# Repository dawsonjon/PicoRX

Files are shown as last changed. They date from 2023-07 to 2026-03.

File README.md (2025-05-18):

Pi Pico Rx - A crystal radio for the digital age?
=================================

My first step into the world of electronics was with a crystal radio, just like this one. 

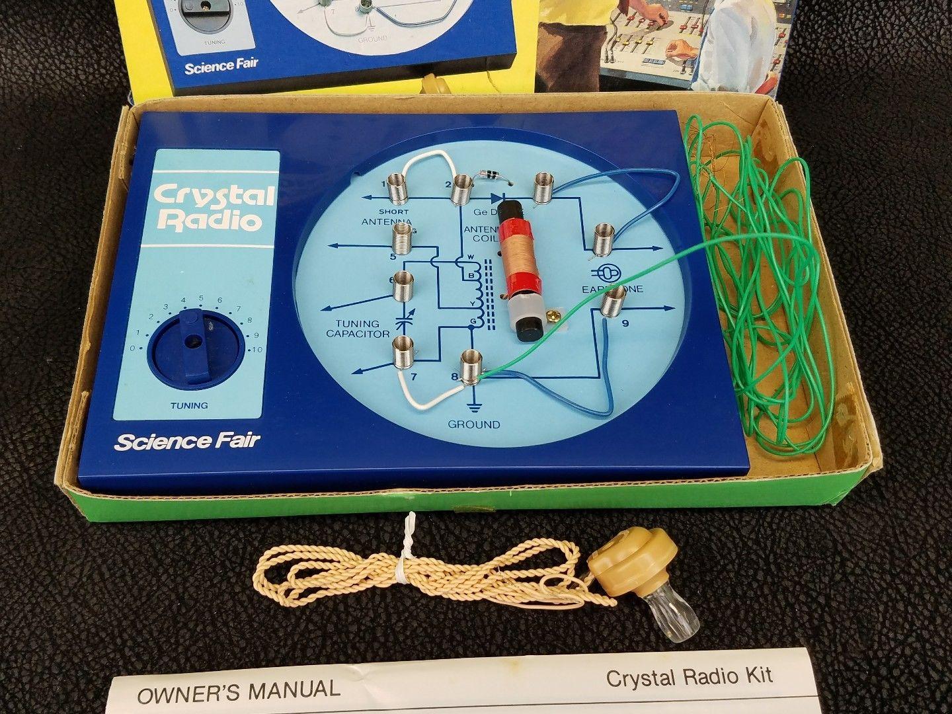
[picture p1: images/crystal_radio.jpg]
crystal radio


Back then, I don't think it has ever occurred to me that I could make a radio myself, so I wasn't expecting it to work. But when I put the earphone in, I was amazed to hear very faint sounds coming through. I couldn't believe that building a radio could be so simple, and the best part was, it didn't need any batteries! That little experience sparked my interest in electronics.

Times have certainly changed since then, and today, we find ourselves in a golden age for electronics enthusiasts. Back in the ninteen eightees, I could have never imagined that my pocket money would one day buy a device with computing power that could have filled an entire room just a few decades ago.

I often wonder how we can still capture that sense of awe and excitement from my first crystal radio experience. Is it still possible to create something simple yet captivating? 

The Pi Pico Rx - may be the answer to that question. While it may not be quite as straightforward as the crystal radio, the Pi Pico Rx presents a remarkably simple solution. Armed with just a [Raspberry Pi Pico](https://www.raspberrypi.com/products/raspberry-pi-pico/), an analogue switch, and an op-amp, we now have the power to construct a capable SDR receiver covering the LW, MW, and SW bands. With the ability to receive signals from halfway around the globe. I can't help but think that my younger self would have been truly impressed!

concept

Features
--------

+ 0 - 30MHz coverage
+ 250kHz bandwidth SDR reciever
+ CW/SSB/AM/FM reception
+ OLED display
+ simple spectrum scope
+ Headphones/Speaker
+ 500 general purpose memories
+ runs on 3 AAA batteries
+ less than 50mA current consumption

Development
-----------

concept

Pi Pico Rx is currently at the experimental prototyping stage, but it does work. [Read the Docs](https://101-things.readthedocs.io/en/latest/radio_receiver.html) for more technical details!

Getting the Code
----------------

You can find a precompiled binary for PiPicoRx [here](https://github.com/dawsonjon/PicoRX/releases). If you want to build from the C++ source files, follow these instructions.

```
  sudo apt install git
  git clone https://github.com/dawsonjon/PicoRX.git
  cd PicoRX
  git submodule init
  git submodule update
```

User Manual
-----------

You can find the user manual for the PiPicoRx [here](https://github.com/dawsonjon/PicoRX/raw/master/user_manual/Pi%20Pico%20Rx%20User%20Manual.pdf).

Install Pi Pico SDK
-------------------

Follow the [Getting started with the Raspberry Pi Pico](https://datasheets.raspberrypi.com/pico/getting-started-with-pico.pdf) quick start guide to install the C/C++ SDK.

```
  sudo apt install wget #if wget not installed
  wget https://raw.githubusercontent.com/raspberrypi/pico-setup/master/pico_setup.sh
  chmod +x pico_setup.sh
  ./pico_setup.sh
```

For windows users, this page provides and [installer](https://www.raspberrypi.com/news/raspberry-pi-pico-windows-installer/) that makes the process much simpler.

Build Projects
--------------

```
  mkdir build
  cd build
  cmake -DPICO_BOARD=pico -DPICO_SDK_PATH=~/pico/pico-sdk ..
  make
```

```
  mkdir build
  cd build
  cmake -DPICO_SDK_PATH=~/pico/pico-sdk -DPICO_BOARD=pico2 -DPICO_PLATFORM=rp2350-arm-s ..
  make
```

```
  mkdir build
  cd build
  cmake -DPICO_SDK_PATH=~/pico/pico-sdk -DPICO_BOARD=pico2 -DPICO_PLATFORM=rp2350-riscv ..
  make
```

Credits
-------

Massive thanks to everybody who has contributed and given feedback on this project. Thanks to
all your efforts, we’re closer than ever to making radio more accessible,
innovative, and community-driven.

The project uses the Universal 8-bit Graphics Library (u8g2) library by
olikraus@gmail.com, the pico_ssd1306 display library by David Schramm and the
ILI934X display driver by Darren Horrocks.

Special Thanks to:

Mariusz Ryndzionek for contributing IQ Imbalance Correction, De-emphasis
filter, USB audio, U8G2 integration, Synronous AM Demodulation and many other
enhancements.

Penfold42 for Gain Calibration, Frequency Scanning, Spectrum Zoom, Multiple home screen
views, Animated Splash Screen, Support for multiple displays/configurations and
many other enhancements.

Robert Nickels (W9RAN) and Jim Reagan (W0CHL) for their support and
encouragements and for the enormous effort they have both put in testing,
debugging, feedback and suggestions.

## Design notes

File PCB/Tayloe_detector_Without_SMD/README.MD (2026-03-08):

A Tayloe Detector Without SMD components
========================================

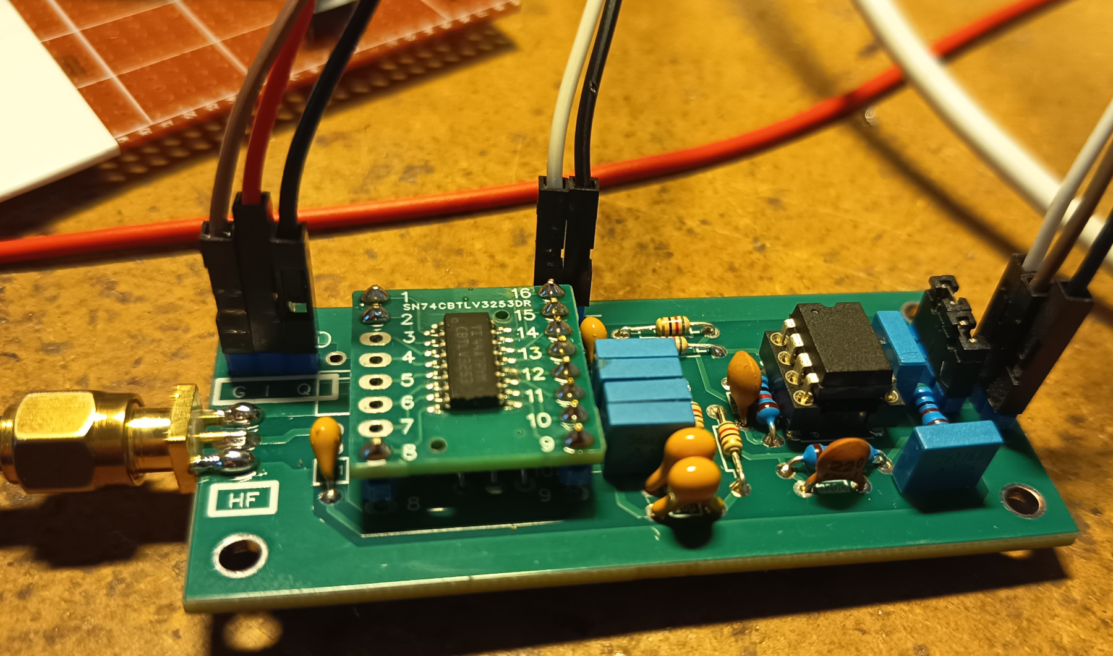
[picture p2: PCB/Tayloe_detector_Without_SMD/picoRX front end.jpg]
picoRX front end


This detector was built using traditional (through-hole) components in order to carry out tests and measurements on PicoRX. It includes the latest improvements to the receiver (anti-aliasing).
The 74CBTLV3253 is mounted on a SOIC16 to DIP16 adapter.

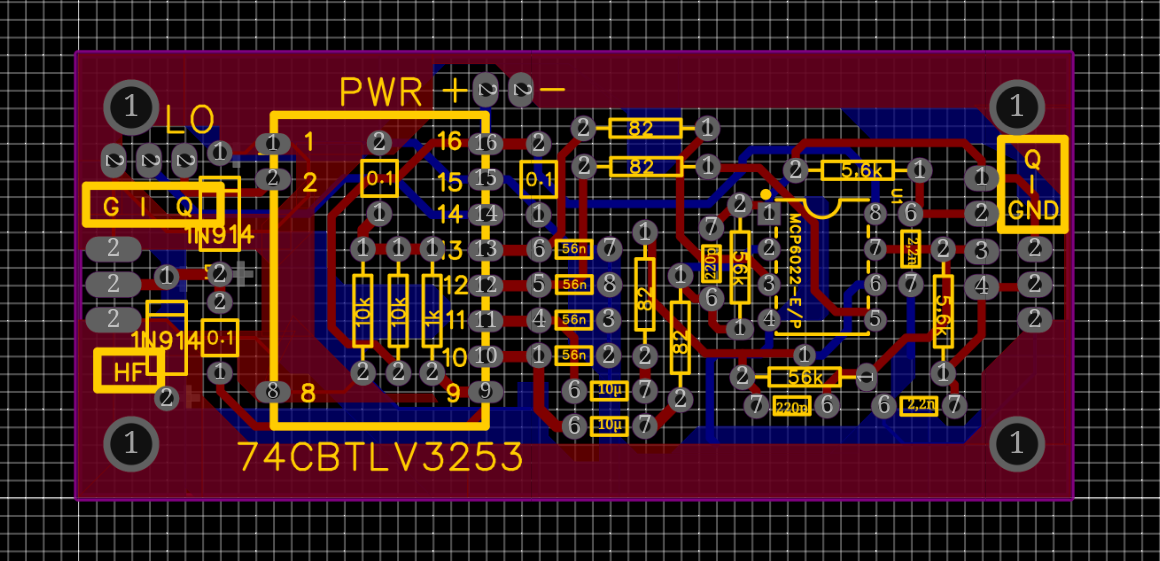
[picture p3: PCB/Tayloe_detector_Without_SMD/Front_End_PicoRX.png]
picoRX front end


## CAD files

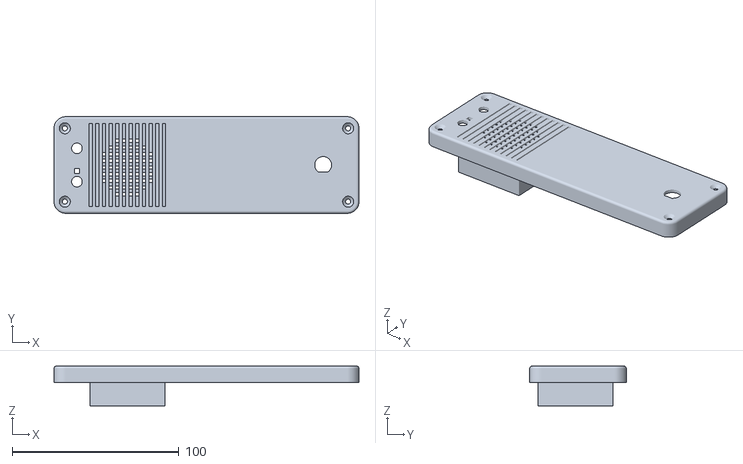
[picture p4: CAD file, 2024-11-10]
enclosure/breadboard_version/breadboard_radio-Partback_panel_tft.stl
183.0 x 58.0 x 24.0

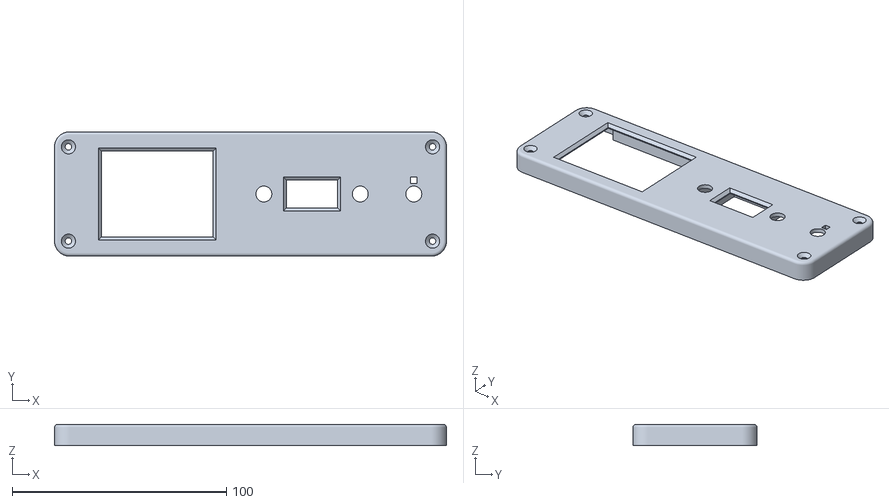
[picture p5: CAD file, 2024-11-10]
enclosure/breadboard_version/breadboard_radio-Partfront_panel_tft.stl
183.0 x 58.0 x 10.0

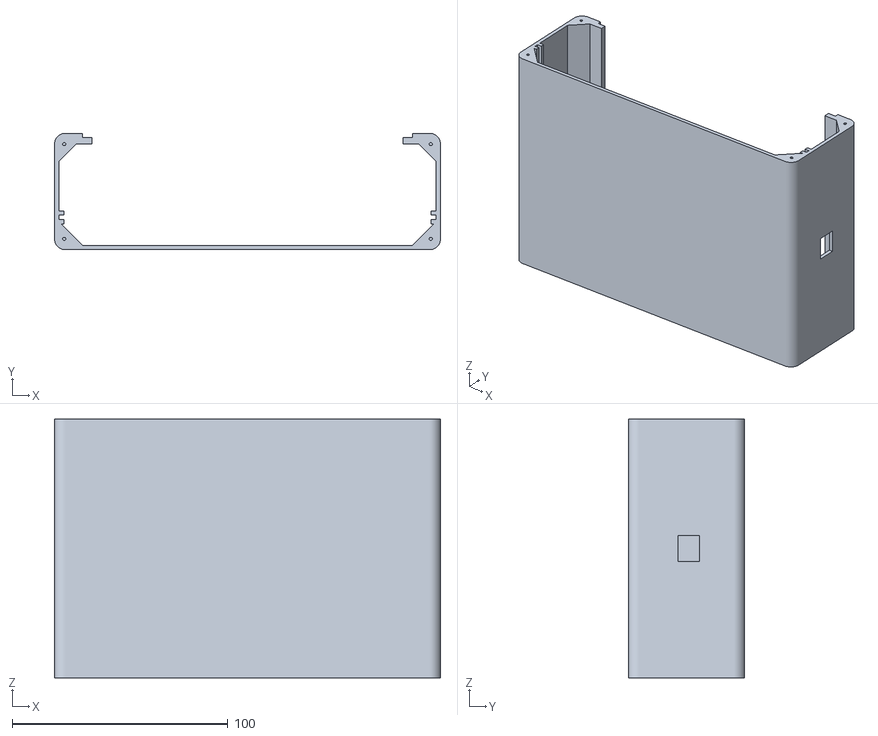
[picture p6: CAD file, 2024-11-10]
enclosure/breadboard_version/breadboard_radio-Partbox.stl
179.0 x 54.0 x 120.0

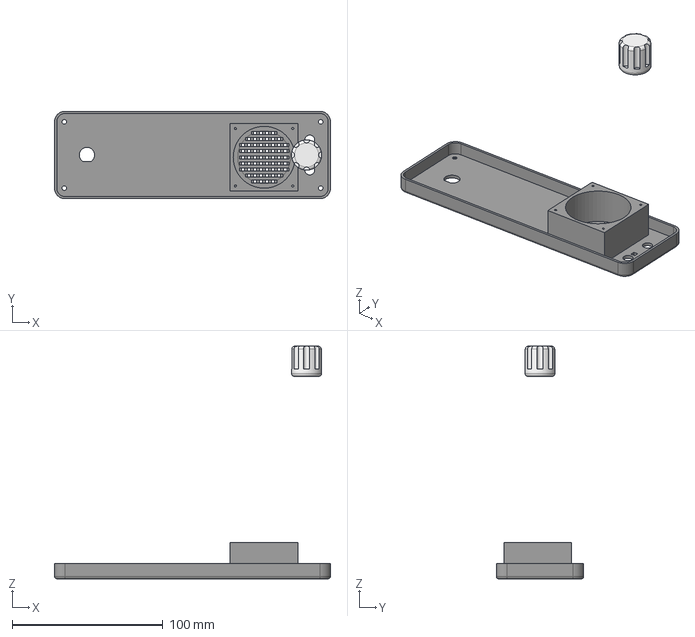
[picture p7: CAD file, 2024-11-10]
enclosure/breadboard_version/breadboard_radio.FCStd
183.0 x 58.0 x 154.2 mm
back_panel_tft
knob

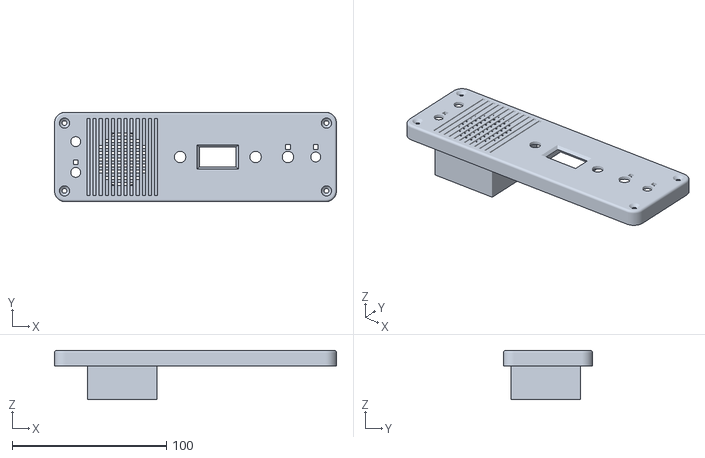
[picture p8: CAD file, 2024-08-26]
enclosure/breadboard_version/breadboard_radio-Partfront_panel.stl
183.0 x 58.0 x 32.0

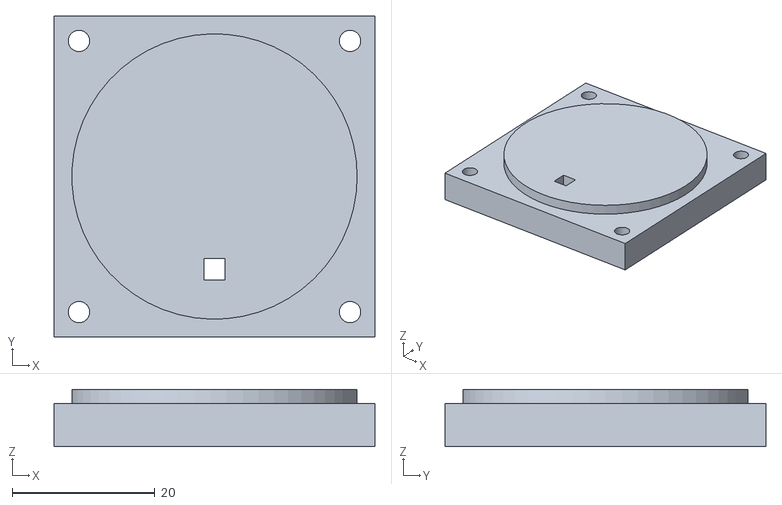
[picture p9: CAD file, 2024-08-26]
enclosure/breadboard_version/breadboard_radio-PartSpeakerLid.stl
45.0 x 45.0 x 8.00

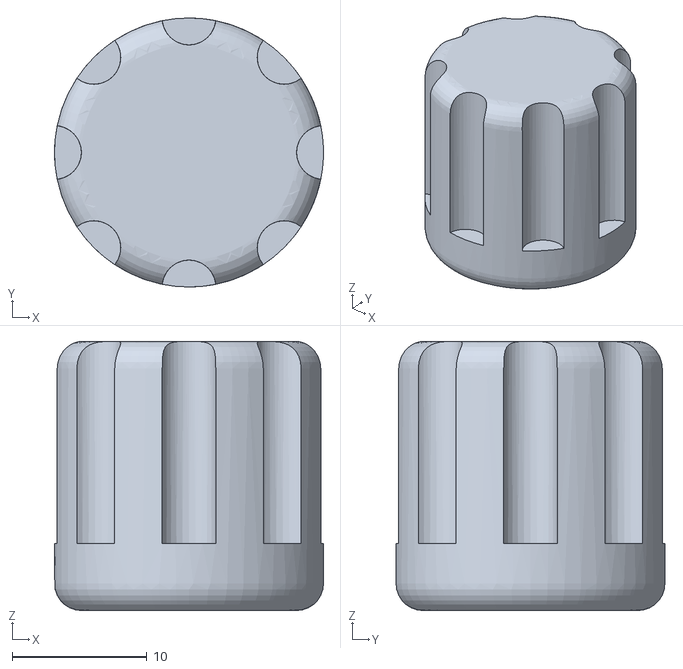
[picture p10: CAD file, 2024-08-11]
enclosure/breadboard_version/breadboard_radio-knob.stl
20.0 x 20.0 x 20.0

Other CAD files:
enclosure/breadboard_version/breadboard_radio-Partback panel.stl
enclosure/breadboard_version/breadboard_radio-Partback_panel.stl

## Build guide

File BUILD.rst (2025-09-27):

Pi Pico Rx - Build Instructions
"""""""""""""""""""""""""""""""

Getting the Code
----------------

.. code::

  sudo apt install git
  git clone https://github.com/dawsonjon/PicoRX.git
  cd PicoRX
  git submodule init
  git submodule update

Install Build Dependencies
--------------------------

Install the following packages using your distributions package manager:

- `cmake`
- `gcc-arm-none-eabi`

For Ubuntu and other Debian based Linux distributions, the following command
line can be used to install all dependencies at once.

.. code::

  sudo apt install git cmake gcc-arm-none-eabi

Install Pi Pico SDK (Optional)
------------------------------

This step is now optional and only necessary if offline (no internet) builds
are desired. If this step is skipped, the configure step of the CMake build will
pull down the necessary Pico SDK dependencies.

Follow the `Getting started with the Raspberry Pi Pico <https://datasheets.raspberrypi.com/pico/getting-started-with-pico.pdf>`_ quick start guide to install the C/C++ SDK.

.. code::

  sudo apt install wget #if wget not installed
  wget https://raw.githubusercontent.com/raspberrypi/pico-setup/master/pico_setup.sh
  chmod +x pico_setup.sh
  ./pico_setup.sh

Build Project
-------------

Build the project using these cmake commands.

.. code::

  mkdir build
  cd build
  cmake -DPICO_BOARD=pico ..
  make

**NOTE**: When using the installed SDK described in the previous section, ensure
the ``PICO_SDK_PATH`` environment variable exists on your path by running:
``echo ${PICO_SDK_PATH}``. If the output is empty, refresh the environment by
either starting a new shell or by running: ``source ~/.bashrc``.

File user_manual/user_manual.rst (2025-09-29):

.. header::
  Pi Pico Rx User Manual

.. footer::
  Revision 2 Copyright (C) Jonathan P Dawson 2025

  Page ###Page### of ###Total###

Pi Pico RX - User Manual
########################

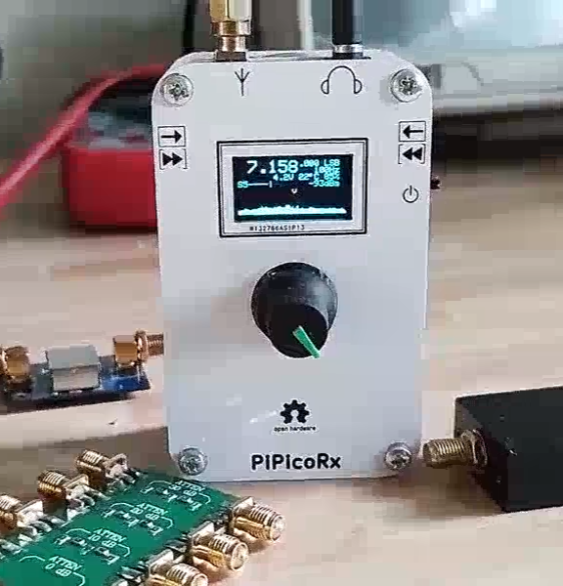
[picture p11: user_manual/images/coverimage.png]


.. raw:: pdf

   PageBreak

.. sectnum::

.. contents::

.. raw:: pdf

   PageBreak

Home Screen
===================

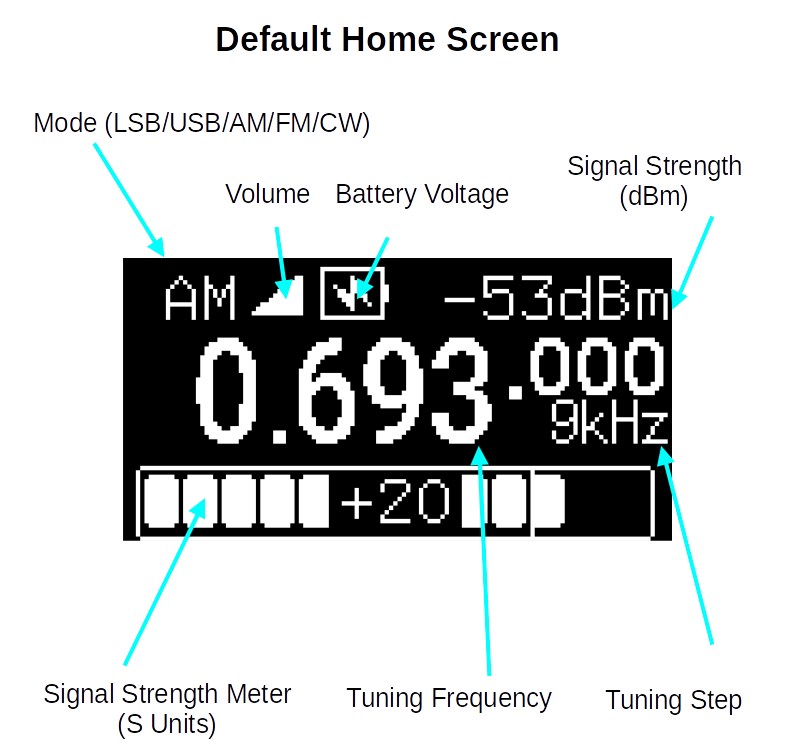
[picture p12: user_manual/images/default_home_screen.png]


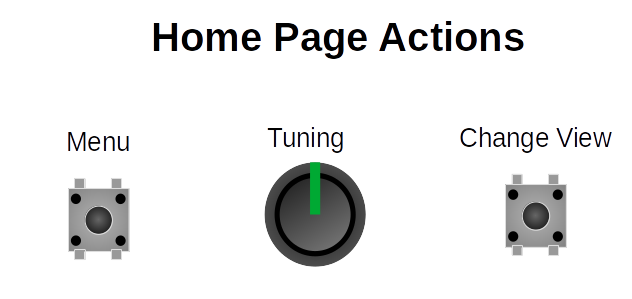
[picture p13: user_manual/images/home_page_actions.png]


Views
------

Views include spectrum scope, waterfall, status info, memory scan, frequency scan etc.

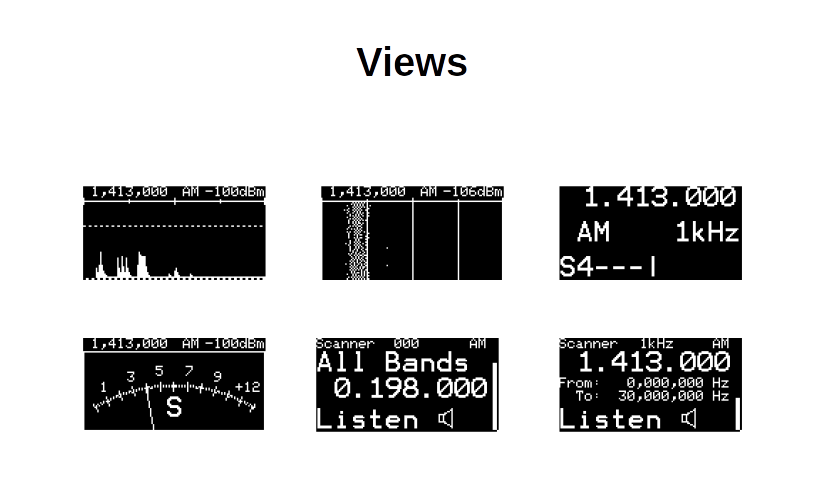
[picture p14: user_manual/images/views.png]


Tuning
------

+-------------------------------------------+----------------------------------------+
| Shortcut                                  |          Description                   |
+===========================================+========================================+
| Encoder Rotate                            |        Tuning Up/Down                  |
+-------------------------------------------+----------------------------------------+
| Encoder Rotate + Menu held                |      Tuning Up/Down x10                |
+-------------------------------------------+----------------------------------------+
| Encoder Rotate + Back held                |      Tuning Up/Down /10                |
+-------------------------------------------+----------------------------------------+
| Encoder Rotate + Menu held + Back held    |      Tuning Up/Down x100               |
+-------------------------------------------+----------------------------------------+

Shortcuts
---------

+-------------------------------------------+----------------------------------------+
| Shortcut                                  |          Description                   |
+===========================================+========================================+
| Encoder Rotate                            |        Tuning Up/Down                  |
+-------------------------------------------+----------------------------------------+
| Encoder Rotate + Menu held                |      Tuning Up/Down x10                |
+-------------------------------------------+----------------------------------------+
| Encoder Rotate + Menu held + Back held    |      Tuning Up/Down /10                |
+-------------------------------------------+----------------------------------------+
| Encoder Rotate + Menu held + Back held    |      Tuning Up/Down x100               |
+-------------------------------------------+----------------------------------------+
| Encoder Rotate + Encoder Held             |        Volume Up/Down                  |
+-------------------------------------------+----------------------------------------+
| Encoder Rotate + Encoder Held + Menu Held | Mode Select (AM/AMS/FM/CW/LSB/USB)     |
+-------------------------------------------+----------------------------------------+
| Encoder Rotate + Encoder Held + Back Held |         Squelch Up/Down                |
+-------------------------------------------+----------------------------------------+

.. raw:: pdf

   PageBreak

Auxiliary TFT Display (Optional)
================================

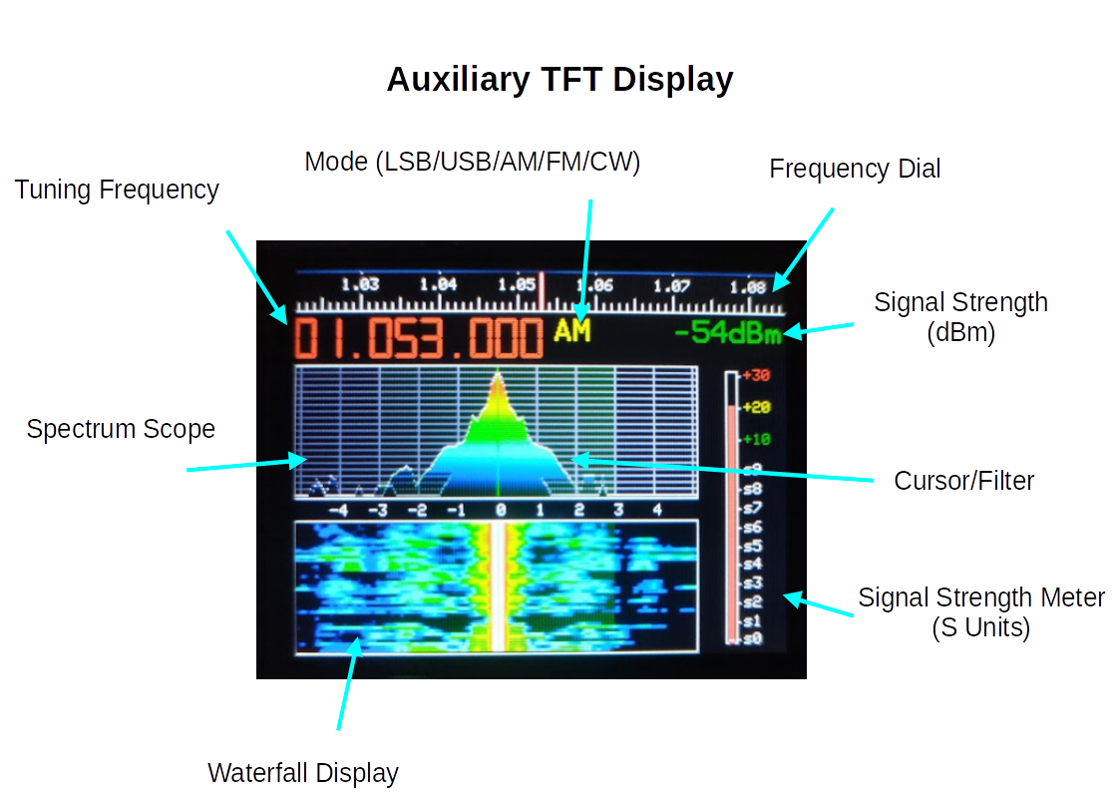
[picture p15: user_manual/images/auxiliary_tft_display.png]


Main Menu
=========

Radio functions and configuration are accessed through the main menu.

+------------------+--------------------------+--------------------------------------------------------------------------------------------------------------------+
| Setting          | Range                    | Description                                                                                                        |
+==================+==========================+====================================================================================================================+
| Frequency        | 0-30 MHz                 | Manual Frequency Entry. Selecting a frequency outside the current band will reset the band limits to               |
|                  |                          | allow free-tuning across the full frequency range.                                                                 |
+------------------+--------------------------+--------------------------------------------------------------------------------------------------------------------+
| Memory Recall    | 0-511                    | Select One of 512 memory channels (A channel can be a single frequency or a band of interest)                      |
+------------------+--------------------------+--------------------------------------------------------------------------------------------------------------------+
| Memory Store     | 0-511                    | Save the current frequency, mode etc. in one of 512 memory channels                                                |
+------------------+--------------------------+--------------------------------------------------------------------------------------------------------------------+
| Volume           | 0-9                      | Audio Volume 0=mute                                                                                                |
+------------------+--------------------------+--------------------------------------------------------------------------------------------------------------------+
| Mode             |                          | Receiver mode (AM, AMS, FM, LSB, USB, CW)                                                                          |
+------------------+--------------------------+--------------------------------------------------------------------------------------------------------------------+
| AGC              | Very Slow – Fast, Manual | Automatic gain control adjusts the gain so that weak and strong stations have a similar volume level.              |
|                  |                          | Fast settings respond quickly to changes in signal level, slow settings change more gradually.                     |
|                  |                          | A slow setting might prevent adjustments to gain during gaps in speech. Manual gain control is also                |
|                  |                          | possible, this might be useful when a constant gain is desirable, e.g. when working with digital modes.            |
+------------------+--------------------------+--------------------------------------------------------------------------------------------------------------------+
| AGC Gain         | 0dB to 60dB              | In Manual mode, this settings specifies the gain directly. In other modes, this setting specifies the              |
|                  |                          | maximum gain limit for the AGC.  Note: If you set a low gain value might prevent weak signals being                |
|                  |                          | heard, if the receiver seems deaf, check this setting!                                                             |
+------------------+--------------------------+--------------------------------------------------------------------------------------------------------------------+
| Bandwidth        | Very Narrow – Very Wide  | Adjust the filter bandwidth, a narrow setting reduces background noise and can improve intelligibility             |
|                  |                          | of weak signals. A wider settings allows through a greater range of frequencies giving better sound                |
|                  |                          | quality for strong signals.                                                                                        |
+------------------+--------------------------+--------------------------------------------------------------------------------------------------------------------+
| Squelch          | S0 - S9+30dB             | The squelch function gates background noise. The signal is muted unless the signal strength reaches                |
|                  |                          | a defined level. Squelch can be adjusted to allow signals to be audible when active, but remove                    |
|                  |                          | background noise when inactive.                                                                                    |
+------------------+--------------------------+--------------------------------------------------------------------------------------------------------------------+
| Squelch Timeout  | 50ms-5s                  | This setting specifies the timeout for the squelch function. When a signal falls below the squelch                 |
|                  |                          | threshold it will continue to be heard until the timeout expires.                                                  |
+------------------+--------------------------+--------------------------------------------------------------------------------------------------------------------+
| Noise Reduction  |                          | Noise Reduction Menu                                                                                               |
+------------------+--------------------------+--------------------------------------------------------------------------------------------------------------------+
| Impulse Blanker  |                          | Enable impulse blanker and set threshold. The impulse blanker can mitigate some types of noise (e.g. from car      |
|                  |                          | ignition circuits, electric fences etc. Threshold values vary from 2.0 to 3.0.                                     |
+------------------+--------------------------+--------------------------------------------------------------------------------------------------------------------+
| Auto Notch       | On/Off                   | The automatic notch filter can be used to remove interfering tones. If stable interference is detected             |
|                  |                          | consistently at the same frequency, a narrow notch is enabled to automatically suppress the interference.          |
+------------------+--------------------------+--------------------------------------------------------------------------------------------------------------------+
| De-Emphasis      | Off/50us/75us            | Enable de-emphasis filter                                                                                          |
+------------------+--------------------------+--------------------------------------------------------------------------------------------------------------------+
| Bass             | Off, 5-20dB              | Bass tone control                                                                                                  |
+------------------+--------------------------+--------------------------------------------------------------------------------------------------------------------+
| Treble           | Off, 5-20dB              | Treble tone control                                                                                                |
+------------------+--------------------------+--------------------------------------------------------------------------------------------------------------------+
| IQ-Correction    | On/Off                   | Compensates for differences in phase/magnitude in the IQ inputs. Enable this setting to improve image              |
|                  |                          | rejection (remove mirror frequencies)                                                                              |
+------------------+--------------------------+--------------------------------------------------------------------------------------------------------------------+
| Spectrum         |                          | Spectrum Menu                                                                                                      |
+------------------+--------------------------+--------------------------------------------------------------------------------------------------------------------+
| Aux Display      | Waterfall/SSTV Decode    | Switch between views in auxiliary (TFT) display (if fitted)                                                        |
+------------------+--------------------------+--------------------------------------------------------------------------------------------------------------------+
| Band Start/Stop  | 0-30MHz                  | The band-start and band-stop settings define the tuning range of the current band. The band-start and              |
|                  |                          | band stop settings are stored in memory channels allowing memory channels to hold bands as well as                 |
|                  |                          | individual frequencies.                                                                                            |
+------------------+--------------------------+--------------------------------------------------------------------------------------------------------------------+
| Frequency Step   | 10Hz-100kHz              | Set the default tuning step. Note that fast and slow tuning from /10 to \*100 the nominal frequency                |
|                  |                          | step can be achieved by holding the menu/back buttons.                                                             |
+------------------+--------------------------+--------------------------------------------------------------------------------------------------------------------+
| CW Tone          | 100Hz - 3000Hz           | When received, the CW signal has a very narrow bandwidth close to DC, lower than the range of human hearing.       |
|                  |                          | The CW tone increases the frequency of the CW signal to a frequency that can be heard comfortably A frequency      |
|                  |                          | between 500Hz and 1000Hz is typical.                                                                               |
+------------------+--------------------------+--------------------------------------------------------------------------------------------------------------------+
| USB Stream       | Audio/IQ                 | Two USB streaming modes are supported. In audio mode, the device is configured as a mono USB                       |
|                  |                          | microphone. In this mode, the demodulated audio is streamed via USB, e.g. for sound recording or for               |
|                  |                          | use with digi-mode apps such as fldigi or wsjtx. In IQ mode, raw IQ data is streamed via USB as a                  |
|                  |                          | stereo stream. In this mode the device can be used with SDR software such as quisk or gqrx.                        |
+------------------+--------------------------+--------------------------------------------------------------------------------------------------------------------+
| HW Configuration |                          | The Pi Pico RX is designed to be as flexible as possible to allow different configurations and                     |
|                  |                          | experimentation by constructors. A separate hardware configuration menu is provided to configure the hardware.     |
+------------------+--------------------------+--------------------------------------------------------------------------------------------------------------------+

Spectrum Menu
=============

+------------------+--------------------------+--------------------------------------------------------------------------------------------------------------------+
| Setting          | Range                    | Description                                                                                                        |
+==================+==========================+====================================================================================================================+
| Spectrum Zoom    | 1-4                      | Zoom level for spectrum scope. 1=30kHz, 2=15kHz, 3=7.5kHz, 4=3.75kHz                                               |
+------------------+--------------------------+--------------------------------------------------------------------------------------------------------------------+
| Spectrum         | 1-4                      | Time Domain Smoothing (averaging) 1=least smoothing 4 = most smoothing                                             |
| Smoothing        |                          |                                                                                                                    |
+------------------+--------------------------+--------------------------------------------------------------------------------------------------------------------+

Noise Reduction
===============

+------------------+---------------------------+--------------------------------------------------------------------------------------------------------------------+
| Setting          | Range                     | Description                                                                                                        |
+==================+===========================+====================================================================================================================+
| Enable           | 1-4                       | Zoom level for spectrum scope. 1=30kHz, 2=15kHz, 3=7.5kHz, 4=3.75kHz                                               |
+------------------+---------------------------+--------------------------------------------------------------------------------------------------------------------+
| Noise            | Very Fast - Very Slow     | Timescale for noise estimation. A fast setting allows the algorithms to adapt to fast changes in noise level.      |
| Estimation       |                           | A slow setting gives a more stable noise measurement.                                                              |
+------------------+---------------------------+--------------------------------------------------------------------------------------------------------------------+
| Noise            | Adaptive, Low - Very High | A high setting removes more noise, but may also remove some signal. The adaptive setting removes more noise when   |
| Threshold        |                           | and uses a less agressive setting in low-noise environments.                                                       |
+------------------+---------------------------+--------------------------------------------------------------------------------------------------------------------+

Hardware Configuration Menu
===========================

+--------------------+-------------------------------+------------------------------------------------------------------------------------------------------------+
| Setting            | Range                         |  Description                                                                                               |
+--------------------+-------------------------------+------------------------------------------------------------------------------------------------------------+
| Tuning Options     | None, Tristate, Ground        |  During retuning, the PLL within the Pi Pico is adjusted to allow the closest possible NCO frequency to be |
|                    |                               |  selected. As the PLL is adjusted, the clock speed within the pico temporarily dips, this causes the PWM   |
|                    |                               |  pulses in the audio output to lengthen, causing an audible click or pop. To mitigate against this, the    |
|                    |                               |  PWM output can be disabled during tuning. There are 2 methods to achieve this, the GPIO pin can be either |
|                    |                               |  tristated, or grounded. The grounding method gives slightly improved click suppression at the expense of  |
|                    |                               |  tuning speed.                                                                                             |
+--------------------+-------------------------------+------------------------------------------------------------------------------------------------------------+
| Display Timeout    | Never, 5 seconds – 4 minutes  |  Display turns off after a period of inactivity. This can be useful for power saving when running from     |
|                    |                               |  batteries. This may also help prevent noise being generated by the display being received.                |
+--------------------+-------------------------------+------------------------------------------------------------------------------------------------------------+
| Regulator Mode     | FM/PWM                        |  The Pi Pico contains a switched-mode regulator. Under light loading, the regulator can switch into a FM   |
|                    |                               |  mode to save power, this does however increase supply ripple. The PWM setting reduces supply ripple.      |
+--------------------+-------------------------------+------------------------------------------------------------------------------------------------------------+
| Reverse Encoder    | On/Off                        |  This allows the direction of the encoder to be reversed (clockwise/anticlockwise). This allows for        |
|                    |                               |  variations in hardware construction where the encoder is wired in a different configuration.              |
+--------------------+-------------------------------+------------------------------------------------------------------------------------------------------------+ 
| Encoder Resolution | On/Off                        |  Allows higher resolution rotary encoders to be used.                                                      |
+--------------------+-------------------------------+------------------------------------------------------------------------------------------------------------+
| Swap IQ            | On/Off                        |  Swap the I/Q ADC input channels. Can be used to correct for a difference in wiring of the LO inputs,      |
|                    |                               |  or IQ inputs. It causes the received spectrum to be reversed so that positive frequencies become negative |
|                    |                               |  and vice-versa. This is also useful for checking image rejection.                                         |
+--------------------+-------------------------------+------------------------------------------------------------------------------------------------------------+
| Gain Cal           | 1-100dB                       |  Specifies the gain of the receiver, this is used by the software to calculate the signal strength for the |
|                    |                               |  S-meter and dBm signal strength. The breadboard version of the receiver with default components has a     |
|                    |                               |  gain of 57dB. Constructors may use alternative gain values, additional filters or preamplifiers. This     |
|                    |                               |  setting also allows the S-meter to be calibrated so that it reads the correct signal strength with a      |
|                    |                               |  known input signal.                                                                                       |
+--------------------+-------------------------------+------------------------------------------------------------------------------------------------------------+
| Freq Cal           | -100 to +100 ppm              |  Allows oscillator frequency to be calibrated to account for process variations in the pi-pico crystal     |
|                    |                               |  oscillator. Frequency can be tuned using a reference oscillator or frequency counter. It may also be      |
|                    |                               |  possible to calibrate by “zero-beating” a station with a known carrier frequency e.g. a broadcast AM      |
|                    |                               |  staio or a reference station such as WWV.                                                                 |
|                    |                               |                                                                                                            |
|                    |                               |  The reciever included a frequency measurement facility, that measures the difference between the recieved |
|                    |                               |  carrier and the tuned frequency. The frequency measurement process takes around 2 seconds. Indicator      |
|                    |                               |  arrows `<` and `>` indicate whether the PPM setting needs to be increased or decreased.                   |
+--------------------+-------------------------------+------------------------------------------------------------------------------------------------------------+
| Flip OLED          | On/Off                        |  Allows the display to be flipped horizontally, this may be useful to constructors who need to place the   |
|                    |                               |  display in a different orientation. Only landscape orientations are supported.                            |
+--------------------+-------------------------------+------------------------------------------------------------------------------------------------------------+
| OLED Type          | SSD1306/SH1106                |  Allows different types of OLED display to be used. I2C OLED displays using SD1306 and SH1106 driver chips |
|                    |                               |  are supported.                                                                                            |
+--------------------+-------------------------------+------------------------------------------------------------------------------------------------------------+
| Display Contrast   | 0 to 15                       |  Allows contrast of OLED display to be adjusted. Lower values reduce power consumption, higher values      |
|                    |                               |  improve readability in bright surroundings.                                                               |
+--------------------+-------------------------------+------------------------------------------------------------------------------------------------------------+
| TFT Settings       | Off, Rotation 1-8.            |  An optional SPI TFT (ili9341) display can be connected to provide an enhanced waterfall/spectrum scope.   |
|                    |                               |  By default the secondary TFT display is disabled. To allow for variations in hardware, 8 different        |
|                    |                               |  rotation settings are provided.                                                                           |
+--------------------+-------------------------------+------------------------------------------------------------------------------------------------------------+
| TFT Colour         | RGB/BGR                       |  Some displays swap RGB and BGR colour order. The seven-segment display should be red, if your's is blue   |
|                    |                               |  change this setting.                                                                                      |
+--------------------+-------------------------------+------------------------------------------------------------------------------------------------------------+
| TFT Invert         | Normal/Invert                 |  Some displays invert colours (like a negative). The background should be black, if your's is white change |
|                    |                               |  this setting.                                                                                             |
+--------------------+-------------------------------+------------------------------------------------------------------------------------------------------------+
| TFT Driver         | Normal/Alternate              |  Lots of variation exists between ILI9341 displays, two drivers are included you may get better results by |
|                    |                               |  trying an alternate driver.                                                                               |
+--------------------+-------------------------------+------------------------------------------------------------------------------------------------------------+
| Bands              | Band 1-5 0 to 32MHz           |  Pi Pico Rx provides 3 GPIO outputs to control up to 8 band filters. The default settings are intended to  |
|                    |                               |  work with the PCB version and provide a good compromise for a general coverage receiver. The boundary     |
|                    |                               |  between the bands can configured through this menu, this allows constructors to define their own custom   |
|                    |                               |  bands (e.g. one band-pass filter for each amateur radio band).                                            |
+--------------------+-------------------------------+------------------------------------------------------------------------------------------------------------+
| IF Mode            | Nearest, Lower, Upper         |  Pi Pico Rx uses a low IF, typically a few kHz from the tuned signal. This eliminates noise that occurs    |
|                    |                               |  close to the local oscillator frequency due to 1/F effects etc. By default, the NCO is tuned to the       |
|                    |                               |  closest achieveable frequency to the requested IF. The lower and upper mode force the NCO to be tuned     |
|                    |                               |  below or above the chosen frequency. Changing the IF mode may help eliminate interference.                |
+--------------------+-------------------------------+------------------------------------------------------------------------------------------------------------+
| IF Frequency       | 0-12kHz                       |  The IF frequency may be adjusted. This might be useful if you are experiencing interfering signals. It    |
|                    |                               |  is often possible to mitigate interference by changing the IF frequency, which will allow interfering     |
|                    |                               |  signals to be moved away from the tuned frequency under some circumstances.                               |
+--------------------+-------------------------------+------------------------------------------------------------------------------------------------------------+
| External NCO       | Off/On                        |  Enable (experimental) support for external SI5351 NCO. This mode is intended mainly for performance       |
|                    |                               |  evaluation purposes, an external NCO is not required to operate the Pi Pico Rx.                           |
+--------------------+-------------------------------+------------------------------------------------------------------------------------------------------------+
| USB Upload         |                               |  Places Pi Pico into USB firmware upload mode. The device appears as a USB drive, and can be upgraded by   |
|                    |                               |  dropping writing a .uf2 firmware image. This is equivalent to holding the pico push-button during power   |
|                    |                               |  on.                                                                                                       |
+--------------------+-------------------------------+------------------------------------------------------------------------------------------------------------+

Scanning
========

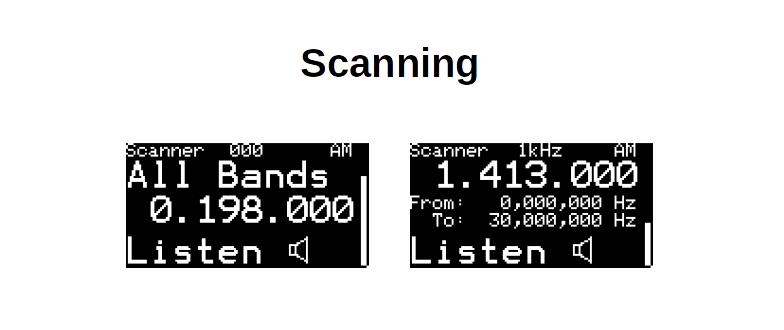
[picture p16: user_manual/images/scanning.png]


Pi Pico RX provides a scan feature, the scan feature can be accessed as a
separate “home screen view”. (Different views can be selected by pressing the
“back” button on the home screen.

There are 2 scanning modes, frequency scan and memory scan. In frequency scan
mode, the receiver searches for signals in the current band frequency range
(e.g. 20m SSB band). In memory scan mode, the receiver searches memory channels
for active signals.

The encoder controls both the direction and speed of the search.

In both modes, the squelch setting is used to determine the threshold level, if
the signal strength exceeds the squelch threshold, the search is halted.
Searching can be continued by rotating the encoder.

The current signal strength and squelch level are indicated by a vertical bar
on the right hand side.

CAT Control
===========

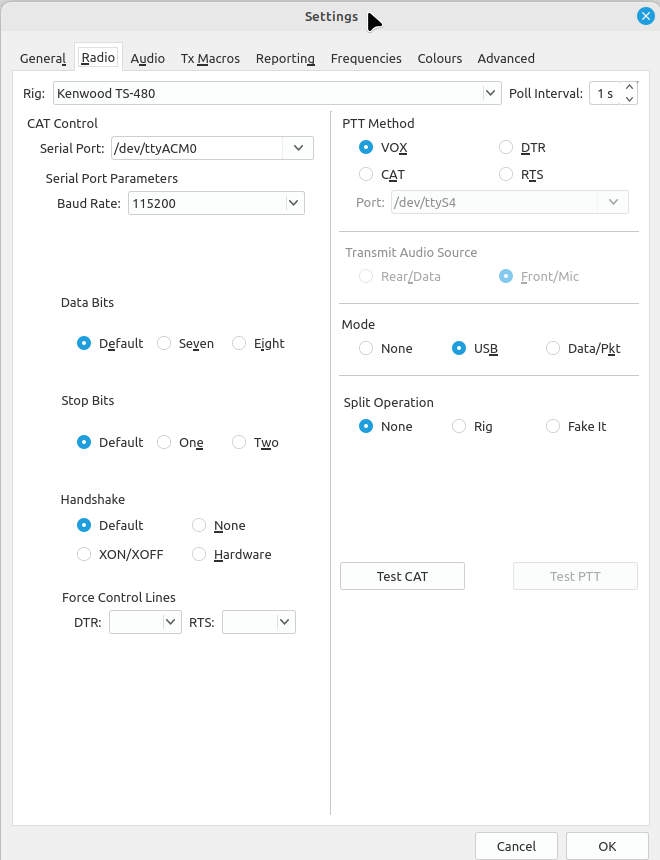
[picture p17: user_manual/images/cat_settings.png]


Cat control is provided through a USB serial port interface. The Pi Pico Rx
emulates a subset Kenwood TS-480. The CAT interface allows the receiver to be
controlled via a host device by software such as grig, wsjtx and fldigi.

USB Audio
=========

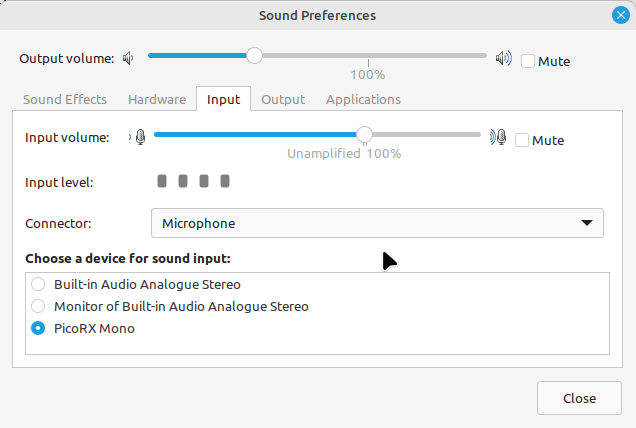
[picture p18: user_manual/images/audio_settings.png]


The Pi Pico Rx supports USB audio, and when connected should appear as a USB
microphone. This allows a host device to easily make audio recordings (e.g.
using audacity), and is compatible with software such as wsjtx, fldigi and
QSSTV. When combined with USB cat control allows a fully functional PC
connection using only a single USB cable. The direct digital audio connection
provides superior audio quality compared to an analogue connection using a
sound card.

Filter Bandwidth
================

The bandwidth of the audio filter can be varied according to preference. The
bandwidth settings can be selected from "very narrow" to "very wide". The
precise meaning of each setting depends on the mode in use. The following table
gives the approximate bandwidth of each setting depending on mode.

+-------------+------------+-------------+------------+------------+------------+----------+
|             | AM  (kHz)  |  AMS  (kHz) | LSB  (kHz) | USB (kHz)  |  FM  (kHz) | CW  (Hz) |
+-------------+------------+-------------+------------+------------+------------+----------+
| Very Narrow | 4.6        | 4.6         | 1.6        | 1.6        | 7.4        | 100      |
+-------------+------------+-------------+------------+------------+------------+----------+
| Narrow      | 5.3        | 5.3         | 2          | 2          | 8.1        | 400      |
+-------------+------------+-------------+------------+------------+------------+----------+
| Normal      | 6          | 6           | 2.3        | 2.3        | 8.8        | 600      |
+-------------+------------+-------------+------------+------------+------------+----------+
| Wide        | 7.4        | 7.4         | 2.7        | 2.7        | 9.5        | 800      |
+-------------+------------+-------------+------------+------------+------------+----------+
| Very Wide   | 14.9       | 14.9        | 3          | 3          | 10.2       | 1100     |
+-------------+------------+-------------+------------+------------+------------+----------+

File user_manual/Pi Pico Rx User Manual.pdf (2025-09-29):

# Pi Pico RX - User Manual

Pi Pico Rx User Manual


Revision 2 Copyright (C) Jonathan P Dawson 2025

# Contents

1 Home Screen | 3
1.1 Views | 4
1.2 Tuning | 4
1.3 Shortcuts | 4
2 Auxiliary TFT Display (Optional) | 6
3 Main Menu | 6
4 Spectrum Menu | 8
5 Noise Reduction | 8
6 Hardware Configuration Menu | 8
7 Scanning | 10
8 CAT Control | 11
9 USB Audio | 11
10 Filter Bandwidth | 12

Revision 2 Copyright (C) Jonathan P Dawson 2025

# 1 Home Screen

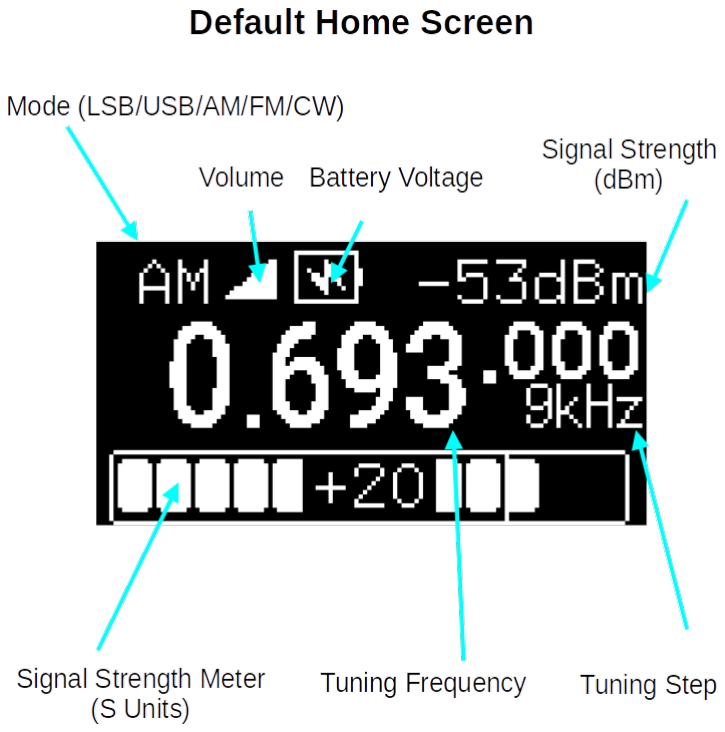
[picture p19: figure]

Revision 2 Copyright (C) Jonathan P Dawson 2025

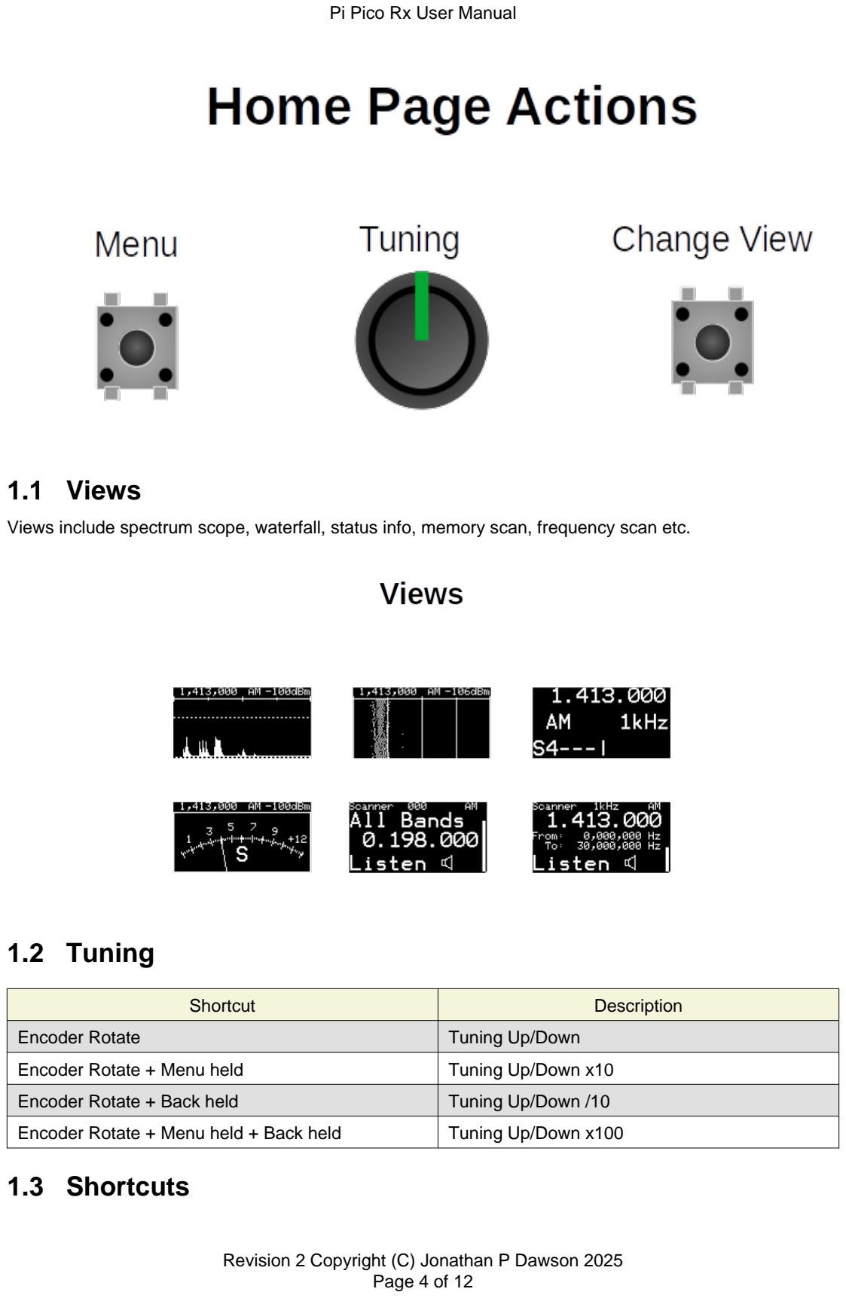
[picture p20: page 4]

## 1.1 Views

Views include spectrum scope, waterfall, status info, memory scan, frequency scan etc.

## 1.2 Tuning

Shortcut | | Description
Encoder Rotate | Tuning Up/Down
Encoder Rotate + Menu held | Tuning Up/Down x10
Encoder Rotate + Back held | Tuning Up/Down /10
Encoder Rotate + Menu held + Back held | Tuning Up/Down x100

## 1.3 Shortcuts

Revision 2 Copyright (C) Jonathan P Dawson 2025

Shortcut | | Description
Encoder Rotate | Tuning Up/Down
Encoder Rotate + Menu held | Tuning Up/Down x10
Encoder Rotate + Menu held + Back held | Tuning Up/Down /10
Encoder Rotate + Menu held + Back held | Tuning Up/Down x100
Encoder Rotate + Encoder Held | Volume Up/Down
Encoder Rotate + Encoder Held + Menu Held | Mode Select (AM/AMS/FM/CW/LSB/USB)
Encoder Rotate + Encoder Held + Back Held | Squelch Up/Down

Revision 2 Copyright (C) Jonathan P Dawson 2025

# 2 Auxiliary TFT Display (Optional)

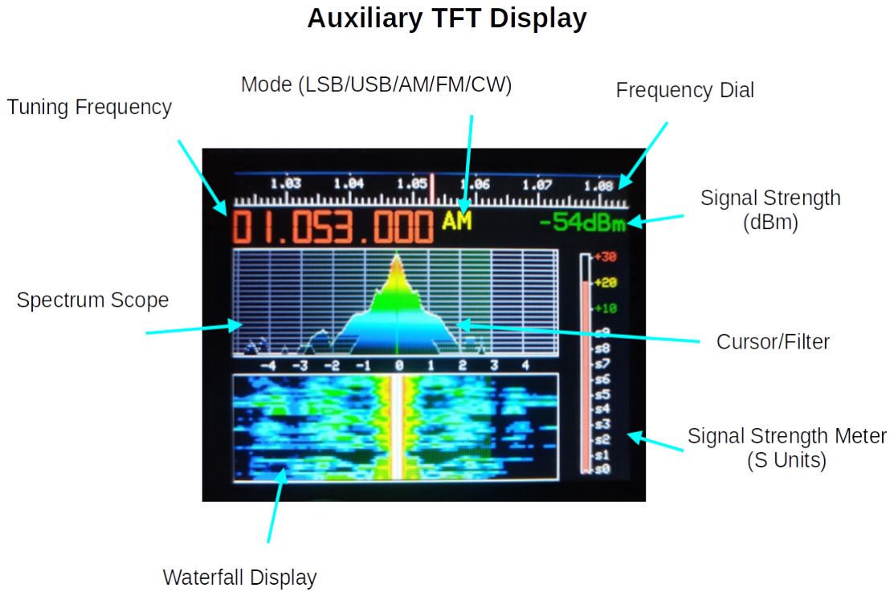
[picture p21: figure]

# 3 Main Menu

Radio functions and configuration are accessed through the main menu.

Setting | | | Range | Description
Frequen cy | 0-30 MHz | Manual Frequency Entry. Selecting a frequency outside the current band will reset the band limits to allow free-tuning across the full frequency range.
Memory Recall | 0-511 | Select One of 512 memory channels (A channel can be a single frequency or a band of interest)
Memory Store | 0-511 | Save the current frequency, mode etc. in one of 512 memory channels
Volume | 0-9 | Audio Volume 0=mute
Mode | | Receiver mode (AM, AMS, FM, LSB, USB, CW)
AGC | Very Slow – Fast, Manual | Automatic gain control adjusts the gain so that weak and strong stations have a similar volume level. Fast settings respond quickly to changes in signal level, slow settings change more gradually. A slow setting might prevent adjustments to gain during gaps in speech. Manual gain control is also possible, this might be useful when a constant gain is desirable, e.g. when working with digital modes.

Revision 2 Copyright (C) Jonathan P Dawson 2025

AGC Gain | 0dB to 60dB | In Manual mode, this settings specifies the gain directly. In other modes, this setting specifies the maximum gain limit for the AGC. Note: If you set a low gain value might prevent weak signals being heard, if the receiver seems deaf, check this setting!
Bandwid th | Very Narrow – Very Wide | Adjust the filter bandwidth, a narrow setting reduces background noise and can improve intelligibility of weak signals. A wider settings allows through a greater range of frequencies giving better sound quality for strong signals.
Squelch | S0 - S9+30dB | The squelch function gates background noise. The signal is muted unless the signal strength reaches a defined level. Squelch can be adjusted to allow signals to be audible when active, but remove background noise when inactive.
Squelch Timeout | 50ms-5s | This setting specifies the timeout for the squelch function. When a signal falls below the squelch threshold it will continue to be heard until the timeout expires.
Noise R eduction | | Noise Reduction Menu
Impulse Blanker | | Enable impulse blanker and set threshold. The impulse blanker can mitigate some types of noise (e.g. from car ignition circuits, electric fences etc. Threshold values vary from 2.0 to 3.0.
Auto Notch | On/Off | The automatic notch filter can be used to remove interfering tones. If stable interference is detected consistently at the same frequency, a narrow notch is enabled to automatically suppress the interference.
De-Emp hasis | Off/50us/75us | Enable de-emphasis filter
Bass | Off, 5-20dB | Bass tone control
Treble | Off, 5-20dB | Treble tone control
IQ-Corre ction | On/Off | Compensates for differences in phase/magnitude in the IQ inputs. Enable this setting to improve image rejection (remove mirror frequencies)
Spectru m | | Spectrum Menu
Aux Display | Waterfall/SST V Decode | Switch between views in auxiliary (TFT) display (if fitted)
Band St art/Stop | 0-30MHz | The band-start and band-stop settings define the tuning range of the current band. The band-start and band stop settings are stored in memory channels allowing memory channels to hold bands as well as individual frequencies.
Frequen cy Step | 10Hz-100kHz | Set the default tuning step. Note that fast and slow tuning from /10 to *100 the nominal frequency step can be achieved by holding the menu/back buttons.
CW Tone | 100Hz -3000Hz | When received, the CW signal has a very narrow bandwidth close to DC, lower than the range of human hearing. The CW tone increases the frequency of the CW signal to a frequency that can be heard comfortably A frequency between 500Hz and 1000Hz is typical.

Revision 2 Copyright (C) Jonathan P Dawson 2025

USB Stream | Audio/IQ | Two USB streaming modes are supported. In audio mode, the device is configured as a mono USB microphone. In this mode, the demodulated audio is streamed via USB, e.g. for sound recording or for use with digi-mode apps such as fldigi or wsjtx. In IQ mode, raw IQ data is streamed via USB as a stereo stream. In this mode the device can be used with SDR software such as quisk or gqrx.
HW Conf iguration | | The Pi Pico RX is designed to be as flexible as possible to allow different configurations and experimentation by constructors. A separate hardware configuration menu is provided to configure the hardware.

# 4 Spectrum Menu

Setting | Range | Description
Spectru m Zoom | 1-4 | Zoom level for spectrum scope. 1=30kHz, 2=15kHz, 3=7.5kHz, 4=3.75kHz
Spectru m Smoot hing | 1-4 | Time Domain Smoothing (averaging) 1=least smoothing 4 = most smoothing

# 5 Noise Reduction

Setting | Range | Description
Enable | 1-4 | Zoom level for spectrum scope. 1=30kHz, 2=15kHz, 3=7.5kHz, 4=3.75kHz
Noise Es timation | Very Fast -Very Slow | Timescale for noise estimation. A fast setting allows the algorithms to adapt to fast changes in noise level. A slow setting gives a more stable noise measurement.
Noise Th reshold | Adaptive, Low - Very High | A high setting removes more noise, but may also remove some signal. The adaptive setting removes more noise when and uses a less agressive setting in low-noise environments.

# 6 Hardware Configuration Menu

Setting | Range | Description
Tuning Options | None, Tristate, Ground | During retuning, the PLL within the Pi Pico is adjusted to allow the closest possible NCO frequency to be selected. As the PLL is adjusted, the clock speed within the pico temporarily dips, this causes the PWM pulses in the audio output to lengthen, causing an audible click or pop. To mitigate against this, the PWM output can be disabled during tuning. There are 2 methods to achieve this, the GPIO pin can be either tristated, or grounded. The grounding method gives slightly improved click suppression at the expense of tuning speed.
Display Timeout | Never, 5 seconds – 4 minutes | Display turns off after a period of inactivity. This can be useful for power saving when running from batteries. This may also help prevent noise being generated by the display being received.

Revision 2 Copyright (C) Jonathan P Dawson 2025

Regulator Mode | FM/PWM | The Pi Pico contains a switched-mode regulator. Under light loading, the regulator can switch into a FM mode to save power, this does however increase supply ripple. The PWM setting reduces supply ripple.
Reverse Encoder | On/Off | This allows the direction of the encoder to be reversed (clockwise/anticlockwise). This allows for variations in hardware construction where the encoder is wired in a different configuration.
Encoder Resolutio n | On/Off | Allows higher resolution rotary encoders to be used.
Swap IQ | On/Off | Swap the I/Q ADC input channels. Can be used to correct for a difference in wiring of the LO inputs, or IQ inputs. It causes the received spectrum to be reversed so that positive frequencies become negative and vice-versa. This is also useful for checking image rejection.
Gain Cal | 1-100dB | Specifies the gain of the receiver, this is used by the software to calculate the signal strength for the S-meter and dBm signal strength. The breadboard version of the receiver with default components has a gain of 57dB. Constructors may use alternative gain values, additional filters or preamplifiers. This setting also allows the S-meter to be calibrated so that it reads the correct signal strength with a known input signal.
Freq Cal | -100 to +100 ppm | Allows oscillator frequency to be calibrated to account for process variations in the pi-pico crystal oscillator. Frequency can be tuned using a reference oscillator or frequency counter. It may also be possible to calibrate by “zero-beating” a station with a known carrier frequency e.g. a broadcast AM staio or a reference station such as WWV. The reciever included a frequency measurement facility, that measures the difference between the recieved carrier and the tuned frequency. The frequency measurement process takes around 2 seconds. Indicator arrows < and > indicate whether the PPM setting needs to be increased or decreased.
Flip OLED | On/Off | Allows the display to be flipped horizontally, this may be useful to constructors who need to place the display in a different orientation. Only landscape orientations are supported.
OLED Type | SSD1306/SH110 6 | Allows different types of OLED display to be used. I2C OLED displays using SD1306 and SH1106 driver chips are supported.
Display Contrast | 0 to 15 | Allows contrast of OLED display to be adjusted. Lower values reduce power consumption, higher values improve readability in bright surroundings.
TFT Settings | Off, Rotation 1-8. | An optional SPI TFT (ili9341) display can be connected to provide an enhanced waterfall/spectrum scope. By default the secondary TFT display is disabled. To allow for variations in hardware, 8 different rotation settings are provided.
TFT Colour | RGB/BGR | Some displays swap RGB and BGR colour order. The seven-segment display should be red, if your's is blue change this setting.

Revision 2 Copyright (C) Jonathan P Dawson 2025

TFT Invert | Normal/Invert | Some displays invert colours (like a negative). The background should be black, if your's is white change this setting.
TFT Driver | Normal/Alternate | Lots of variation exists between ILI9341 displays, two drivers are included you may get better results by trying an alternate driver.
Bands | Band 1-5 0 to 32MHz | Pi Pico Rx provides 3 GPIO outputs to control up to 8 band filters. The default settings are intended to work with the PCB version and provide a good compromise for a general coverage receiver. The boundary between the bands can configured through this menu, this allows constructors to define their own custom bands (e.g. one band-pass filter for each amateur radio band).
IF Mode | Nearest, Lower, Upper | Pi Pico Rx uses a low IF, typically a few kHz from the tuned signal. This eliminates noise that occurs close to the local oscillator frequency due to 1/F effects etc. By default, the NCO is tuned to the closest achieveable frequency to the requested IF. The lower and upper mode force the NCO to be tuned below or above the chosen frequency. Changing the IF mode may help eliminate interference.
IF Freque ncy | 0-12kHz | The IF frequency may be adjusted. This might be useful if you are experiencing interfering signals. It is often possible to mitigate interference by changing the IF frequency, which will allow interfering signals to be moved away from the tuned frequency under some circumstances.
External NCO | Off/On | Enable (experimental) support for external SI5351 NCO. This mode is intended mainly for performance evaluation purposes, an external NCO is not required to operate the Pi Pico Rx.
USB Upload | | Places Pi Pico into USB firmware upload mode. The device appears as a USB drive, and can be upgraded by dropping writing a .uf2 firmware image. This is equivalent to holding the pico push-button during power on.

# 7 Scanning

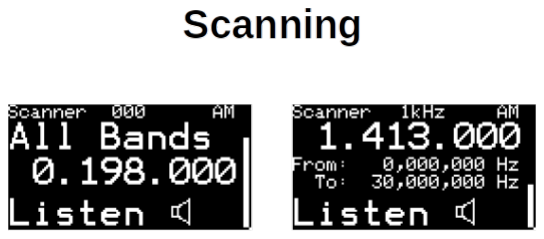
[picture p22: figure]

Pi Pico RX provides a scan feature, the scan feature can be accessed as a separate “home screen view”. (Different views can be selected by pressing the “back” button on the home screen.
There are 2 scanning modes, frequency scan and memory scan. In frequency scan mode, the receiver searches for signals in the current band frequency range (e.g. 20m SSB band). In memory scan mode, the receiver searches memory channels for active signals.

Revision 2 Copyright (C) Jonathan P Dawson 2025

The encoder controls both the direction and speed of the search.
In both modes, the squelch setting is used to determine the threshold level, if the signal strength exceeds the squelch threshold, the search is halted. Searching can be continued by rotating the encoder.
The current signal strength and squelch level are indicated by a vertical bar on the right hand side.

# 8 CAT Control


Cat control is provided through a USB serial port interface. The Pi Pico Rx emulates a subset Kenwood TS-480. The CAT interface allows the receiver to be controlled via a host device by software such as grig, wsjtx and fldigi.

# 9 USB Audio

Revision 2 Copyright (C) Jonathan P Dawson 2025

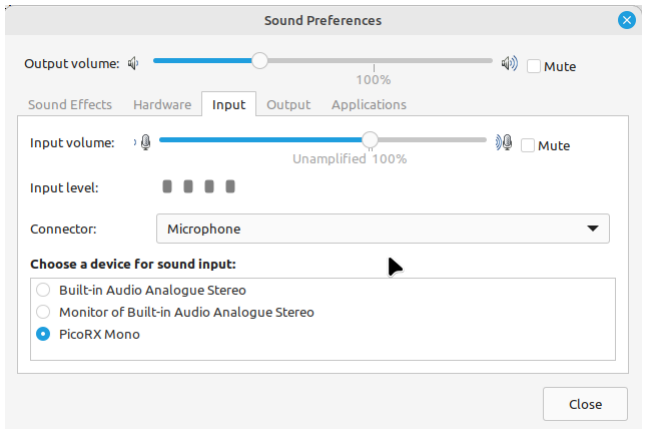
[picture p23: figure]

The Pi Pico Rx supports USB audio, and when connected should appear as a USB microphone. This allows a host device to easily make audio recordings (e.g. using audacity), and is compatible with software such as wsjtx, fldigi and QSSTV. When combined with USB cat control allows a fully functional PC connection using only a single USB cable. The direct digital audio connection provides superior audio quality compared to an analogue connection using a sound card.

# 10 Filter Bandwidth

The bandwidth of the audio filter can be varied according to preference. The bandwidth settings can be selected from "very narrow" to "very wide". The precise meaning of each setting depends on the mode in use. The following table gives the approximate bandwidth of each setting depending on mode.

| AM (kHz) | AMS (kHz) | LSB (kHz) | USB (kHz) | FM (kHz) | CW (Hz)
Very Narrow | 4.6 | 4.6 | 1.6 | 1.6 | 7.4 | 100
Narrow | 5.3 | 5.3 | 2 | 2 | 8.1 | 400
Normal | 6 | 6 | 2.3 | 2.3 | 8.8 | 600
Wide | 7.4 | 7.4 | 2.7 | 2.7 | 9.5 | 800
Very Wide | 14.9 | 14.9 | 3 | 3 | 10.2 | 1100

Revision 2 Copyright (C) Jonathan P Dawson 2025

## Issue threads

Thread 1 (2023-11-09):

QSD Question.

boxerbomb, 2023-11-09:
Why is it that in this design you only have a single RF source going into the FST3253, while in other designs including your own, you also supply an inverted input signal to pin 7?

dawsonjon, 2023-11-09:
Interesting question, there are a few versions of the qsd out there. You might have been refering to this design that uses a transformer as a phase splitter generating a normal and inverted copy of the signal. https://github.com/dawsonjon/OpenXcvr/wiki/Hardware-Design#quadrature-sampling-mixer

In this design I am using a differencing amplifier to achieve the same effect, switching between the inverting and non-inverting inputs of the amplifier instead. I think that the two approaches give equivalent results. The advantage is that it removes a (hand wound and potentially harder to obtain) transformer. I like the simplicity, especially in a stripped down project like this one. There are some designs that use both approaches,  some even use 'proper' differential amplifiers too. I don't think that these changes will make very much difference to the performance though.

I got the idea from this project
https://circuitsalad.com/2020/01/06/compact-si5351-based-sdr/ which is another very minimal receiver. Although this is one of the configurations in Dan Tayloe's paper https://www.norcalqrp.org/files/Tayloe_mixer_x3a.pdf.

boxerbomb, 2023-11-09:
Interesting. Thanks for the information, I might try out a few variations.

Closed 2023-11-09.

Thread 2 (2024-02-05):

Quadrature signals seem to fail on higher frequencies

w9ran, 2024-02-05:
First, thanks very much for this excellent project Jon!    I've built up a board and while it is working I've run into a couple of anomalies,
Note:  I used the 74CBT3253C  as the FST3253 is obsolete and not sold by US distributors any longer, but they are equivalent parts.  (I also did not include the preamp and my antenna is coupled via 100 nF to RF_PREAMP and to the bias network via 10K).

After establishing that it was working on lower bands,  I had poor results trying to tune the 20 meter band - strange noises but no signals at all.  Even when using a signal generator it was completely dead, although it retuning to the lower bands proved the receiver still worked there.

The first thing I do with a QSD is verify that the quadrature clocks were in quadrature- and they were.  However I noticed when I had scope probes temporarily attached to LO_1 and 2, the receiver started to work on 20 meters.   In fact because they are on the corner of the PCB I found I could make the receiver come to life just by touching pin 1 with a finger!  I found experimentally that 33pF was the minimum needed capacitance to ground from either LO_1 or LO_2.    There is kind of an "uncertainty principle" involved since the act of attaching a scope probe to make measurements was changing the behavior of the thing being measured!

My first thought was that the high-speed clock signals might need to be terminated but even with a 390 ohm termination resistor to ground, the same behavior persisted.  The QSD would only work when capacitance is added - I made these two 20 sec. videos to show this with both hand capacitance (via tweezer) even with termination resistors in place, and with the 30pF capacitor:

https://share.icloud.com/photos/0f8v431GzQMLIJ-MR3gZhBL_w
(signal source is 50uV (S9) at 14.1 MHz)

I can hear signals on any frequency up to 12 MHz signal without the capacitor but it is required to hear anything above 13 MHz.   The effect is repeatable and when working, the receiver is able to hear a 2-3uV signal in SSB bandwidth.  There seems to be no gray area - either it works or it doesn't.   Scoping the LO_I pin of the QSD shows no different with and without the capacitor in parallel even though the signal can be heard to appear only with it as in the videos.

Unless there is some subtle difference between 3253 ICs, I'm out of theories -  but I ran into similar issues with my homebrew copy of the uSDX on the higher bands.  It has PCB traces about 1" long connecting the Si5351 and 3253, which I noticed on other radios were made as short as possible.    I had better results when reducing the output current of the Si5351 from 8 to 2mA, all of which suggests a problem with signal reflection on the PCB traces.  If so, the solution would require a complete redesign of the PCB and possibly adding termination resistors.   It would be very helpful to have confirmation using your PicoRX PCB layout.

Within the expected limitations of the DSP filters, the performance is very good when it's working - audio quality through an amplified speaker is excellent.   But this clock business has me baffled!  I'd certainly be interested in knowing if I am alone in what I am seeing!   Thanks and 73,
Bob W9RAN

dawsonjon, 2024-02-06:
Hi Bob,
Thanks very much for your interest in the project, and for taking the time to feed back on your progress. I'm sorry to hear about the problem you have been having. It certainly sounds like a signal integrity issue. I came across similar problems in my first prototype, but I put that down to the long lead lengths and breadboard-style construction. I haven't had any issues since I moved to the PCB and I'm getting reliable reception well beyond 20MHz.

One thing you could try is reducing the slew-rate and drive strength of the LO outputs. It sounds like it would be worth adding some pads for series/parallel termination in the next PCB revision, and the trace lengths could probably be significantly reduced. I could also potentially swap some pins around to make the routing easier.

I have only tried the FST3253 so far, but I have bought a couple of alternative devices to try out. I was considering QS3253QG8 or possibly 74CBTLV3253PW (but at a lower supply voltage). The 74CBT3253C seems like a good candidate too, it wasn't available at my local supplier but it seems like it would be worth trying to see if I can replicate the issue.

Kind Regards
Jon
2E0GXA

w9ran, 2024-02-07:
Thanks for your reply Jon!    I look at DigiKey as kind of the universal reference point since their products are available internationally, and if you sort the dual 4:1 mux/demux parts by 16 pin SO (for easy hand soldering) the 74CBT3253C is what comes to the top.    But TI also made an older "non-C" version in which the /OE pins control both muxes (no individual /OE for each).    The 74CBT3253C that I used on the PicoRx should have identical function to the FST3253, but I went back in my notes from 3 years ago and have posted a summary on my site here for reference:  http://tinyurl.com/3c2rhwyh

On the topic of parts,  I received a Last Time Buy notice on the entire LTC6226/7 family of op-amps, which are evidently being discontinued by ADI.

I'll build another board with termination resistors in LO_1 and LO_2 (ref:  https://resources.pcb.cadence.com/blog/termination-resistors-in-pcb-design)   What really puzzles me is how my receiver works or it doesn't - no gray area where it seems degraded but still works.

I grabbed a couple of scope traces to show the LO waveform with and without the added capacitor:
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

I also see considerable jitter in the quadrature clock duty cycle,  varying from approx 45 to 55%.  I haven't tried to quantify the effect of this, but "to the ear" the performance compares well with other QSDs.

Bob

dawsonjon, 2024-02-08:
Hi Bob,

Thanks very much for sharing these details, I would be very interested to know how you get on with the termination. Its a shame about the LTC6226/7, they seemed like a very useful part. I used an LT6231 in the prototype and that worked well too.

I would expect to see 8ns of Jitter, this is introduced by the PIO's fractional divider. For non-integer clock divisions it aligns to the nearest clock edge which in this case is 125MHz. It could be reduced by overclocking the pico, but I prefer not to do this if I can help it. Its quite hard to quantify the effect of the jitter analytically, we know that the the clock edge can be up to a clock cycle away from where it should be, but how often this happens will depend on the tuned frequency. Also the jitter has a periodic pattern which introduces spurs rather than appearing a phase noise, again the magnitude and position of the spurs depend on the tuned frequency. There will inevitably be some degradation in performance, but in practice it does still seem to be a useable results.

Closed 2024-08-09.

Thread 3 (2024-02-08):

Image/Alias signals

w9ran, 2024-02-08:
I've been hearing signals that should not be where they are heard, such as CW in the middle of the 20 meter SSB band.   I also hear what I know from experience to be the "inverted speech" of an opposite sideband signal.   By using online spotting tools like DX Cluster and RBN I can document this for you.    Here are two screen photos and a short video of the PicoRX alongside my Xiegu G90.   In one, both receivers are  tuned to the actual signal the station is transmitting on, 14.238 MHz USB.   But in one, the Pico Rx is tuned to 14.282 MHz LSB and the same signal can be heard equally well on the short video:

https://share.icloud.com/photos/042VUSVM5L2BdTouaNjXQnCVA

Another example:   The ARRL station W1AW sends code practice daily on specific frequencies including 14.0475 in the 20 meter band.   Here is a short video showing the PicoRX hearing the W1AW transmission when tuned to 14.297 MHz.   I change the frequency on the G90 to change the pitch which makes it clear the two are receiving the same signal:

https://share.icloud.com/photos/04ad-Pb5m6aTgxTEyo_fJKxJg

The antenna in use is an all-band vertical and both receiver are connected via a splitter so the same signal is being presented to both receivers.
73, Bob W9RAN

dawsonjon, 2024-02-08:
Hi Bob,
Thanks again for the very informative feedback. I think there are probably a couple of things that might be going on here.

Firstly, in your example where a signal can be hear equally well at 14.238 MHz and 14.282 MHz, the signals are separated by 44kHz so are both almost certainly within the 250kHz bandwidth of the ADC, this combined with the fact that the signal has an equal amplitude at both frequencies is suggestive of an image. This might be consistent with a missing signal in either the I or Q input channel resulting in a loss of image rejection. Are you seeing signals of similar magnitudes at the I and Q input to the ADC?

Secondly, aliasing is a weakness of this design which I briefly discuss here: https://github.com/dawsonjon/PicoRX/wiki/Hardware-Design#qsd-detector-tayloe-detector The ADC is relying on the QSD to act as an anti-aliasing filter. The QSD is effectively a second order filter so the roll-off is only about 12dB per octave. An aliased signal in the second nyquist region would likely still be heard, but I would expect there to be a noticeable attenuation.

I can think of 3 potential ways to improve the alias rejection:

Firstly a higher-order anti-aliasing filter to the I/Q signals before the ADC, this could be built using low-cost op amps.

Secondly, for the cost of the additional filtering, you might as well use a high quality audio ADC with very good anti-aliasing filters built in, and far better dynamic range.

Thirdly, reduce the bandwidth of the QSD and over-sample. For voice signals an oversampling ratio of 16x could be achieved and that would give very good rejection of aliased signals, the downside is that the frequency resolution of the PIO fractional divider would no-longer be sufficient to cover the HF bands without gaps. There are other approaches to generating the quadrature output that would give much better frequency resolution but  consume more CPU. Alternatively, an external PLL could be be used to generate the quadrature local oscillator, which would have the additional advantage of removing jitter.

I think that combining the second two approaches combining an external PLL and ADC would not only improve the rejection of alias signals but give a much performance all-round. Although I have taken a minimalist approach on the PiPicoRx, it might also be fun to experiment with some of these options in a more uncompromising and high performance receiver.

Kind Regards
Jon

w9ran, 2024-02-09:
>  Are you seeing signals of similar magnitudes at the I and Q input to the ADC?
Jon,
Yes and no - let me explain...
I attached a header to allow monitoring of the IQ signals right at the ADC0 and ADC1 pins.  After several hours looking at the QSD output, both with o'scope and by feeding it into a soundcard on a PC running SDR software,  I'm more puzzled than ever!   The performance of the QSD seems to be frequency-dependent -- here's what I've seen:
1.  The IQ clocks going to the QSD seem to be correct, as I'd previously found, with the exception of the jitter noted.   The effect of the jitter was not immediately obvious to me as I'm still in the process of understanding how the PIO clock works.  But having captured clock waveforms in the range of 4-14 MHz the phase and amplitude at LO_1 and LO_2 are consistent in amplitude and phase.
2.  When a single tone is being received, the expected output from the QSD is the difference between the input frequency and that of the LO, with the two outputs 90 degrees apart.   For example, when tuned to 5000 kHz and a 5001 kHz tone is injected, the QSD outputs should be at 1 kHz.     In my PicoRx this is true - up to a certain frequency, but between 5 and 6 MHz, the output of the Q channel disappears.     One possible cause could be LO-related but as shown here, the 5 and 6 MHz LO clock waveforms seem identical in amplitude and phase:

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

This leaves the QSD itself as the remaining culprit.   I captured the QSD output  while changing the frequency the PicoRx is tuned to and the signal generator to identify where it works and where it doesn't.   Here is a 50uV signal at 5 vs 6 MHz:
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

As seen, the QSD is working perfectly at 5 MHz but not at 6.   This is confirmed by good image suppression (about 1.5 deg phase error) at 5 MHz vs zero suppression at 6 MHz.

3.  To further narrow down the range I worked up from 5 MHz in 100 kHz increments.   On the left, the QSD is working as it should at 5.6 MHz,  becomes erratic at 5.7 MHz and fails at 6.0 MHz:

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

4.  The input level was 50uV for these measurements.  Increasing the input to 500 uV showed an odd result.   The output that appeared to be dead showed output but one channel was badly clipped:

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

5.  After watching the IQ output from the QSD I now see that my earlier theory that adding capacitance was causing the LO clock to work correctly was wrong.  In fact the capacitance somehow tricked the QSD into produce output on one channel, which did bring the receiver to life, but without proper IQ input, thus the images.

6.  Just for reference, I'd note part of the secret to the high performance of Elecraft gear is their roofing filter, but being a QSD the roofing filter in the KX3 is indeed a good active filter using ADA4075-2 as you suggest.   Of course it is not a wideband front-end.
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
w9ran, 2024-06-12:
Jon - thanks for your reply and I agree, the issues seem to be related to small DC voltage offsets that are difficult to measure but which, given the extremely high gain of the amplifier stage,  result in saturation.   I understand that the Pico ADC will require more signal than the soundcard, but that should result in weaker signals, not total deafness, which results when the opamp outputs are driven to the V+ rail.

Since the purpose of the project is learning,  I'll list the various things I tried below in case it is helpful to others:

I have a PC soundcard connected in parallel with the ADC inputs, with no observable degradation of signal.  Due to the shifting low IF of the PicoRX,  I measure the actual LO frequency and then tune the PC software to create a similar low IF offset.  The SDR software will show any images as a mirror-image on the opposite size of center and also gives a relative indication (dBFS) of image suppression.

My hardware is identical to the PicoRX except for test purposes no filters are in line, and the QSD uses a cheaper and easier to solder LM-4562 opamp, just like the uSDX uses.   However mine is running from 5V vs. 12V in the uSDX.   I am using 15nF sampling capacitors rather than 470nF as in the uSDX to obtain wide enough bandwidth for the low IF.

Test 1:  Original PicoRX PC layout with 100 ohm resistors, no capacitors in series with opamp inputs.    With antenna coupled via 100nF but no bias applied, the  sampling capacitor voltages were > 4 VDC and both I and Q opamp outputs were at the 3v3 rail.  No signals can be heard using PicoRX or PC

Test 2:   Attached the 10K bias network with a 0 ohm jumper to the receiver input.  This should have produced a DC bias of Vcc/2 or ~ 1.6V at the sample capacitors but in fact the voltage is ~ 2.09VDC.   (This was also true for the first board I built - the opamps are adding to the DC bias).   The opamp outputs are still saturated at > 3.2VDC and no signals can be heard using PicoRX or PC.

Test 3:  Connected a 1K resistor across the lower 10K of the bias divider.   This reduced the bias voltage to .39VDC at the sample capacitors and the PicoRX came to life.  Signals can be heard on both PicoRX and via soundcard, but the PC shows there is no image suppression at any frequency (and opposite sideband images are heard in the PicoRX audio).

Test 4:   All four 100 ohm resistors were removed and replaced with 100nF capacitors.    This is one of the QSD configurations that Tayloe describes in his paper but on the PicoRX hardware it does not work at all (although it does work with my hardware using LM-4562).    With these series capacitors blocking the opamp voltages, the QSD input bias voltage now measures 1.6VDC as it should.  This voltage is also present on the mux side of the sampling capacitors, but the opamp inputs all measure 4.8VDC and the otuputs are saturated > 3.2V.   No signals can be heard using PicoRX or PC.

Test 5:  The configuration of the Rev 2 PicoRX was implemented, with 100 ohm resistors on the non-inverting inputs and 100 ohms in series with 4.7uF electrolytic capacitors on the inverting inputs  (the resistors were connected to the sampling capacitors and the capacitors to the opamp inputs).  The Vcc/2 bias divider was connected, resulting in 1.72VDC on the sampling capacitors.    The resulting DC voltage at the opamp outputs (i.e. ADC inputs) is in the 120mV range, which allows the PicoRX DSP software to work as it should.

Band conditions have been poor due to solar activity but performance is now good with no images present.   With an external powered speaker, the PicoRX "sounds like" a regular receiver with good AGC action and adequate filtering for most casual listening.

Using the PC soundcard tap I measured the MDS of the QSD using the signal analysis plug-in of SDR#.  At 7 MHz, a -120dBm signal produced 3dB SNR in 500 Hz bandwidth (this is the method used by RSGB, ARRL, and Rob Sherwood).    This is more than sufficient sensitivity to hear any signal on the band, at least in this frequency range.     More testing is planned.

Thank you very much for your efforts and especially for getting
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

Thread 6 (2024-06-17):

Mixer to op-amp connections are different

kholia, 2024-06-17:
The connections in https://dl2man.de/wp-content/uploads/2023/07/truSDX_Main_1_2-1.pdf look like:

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

Note that pin 11 of 3253 goes to the non-inverting terminal of the op-amp.

In this repository, pin 11 goes to the inverting terminal of the op-amp (which is different and opposite).

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

Does this matter? If yes, which way should the pin 11 (and pin 12) connections go?

Thanks for the help!

kholia, 2024-06-18:
Thank you!

From https://files.tapr.org/meetings/DCC_2020/2020DCC_KL7NA.pdf,

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

In my flavor of your `PicoRX` design, I am planning to use the quadrature clocks from Si5351, where the counting order seems to be 0, 1, 2, 3. The `truSDX` design uses quadrature clocks from Si5351 too. I am planning to use the quadrature clocks from Si5351 in hope of better RX performance.

truSDX schematic:

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

The truSDX is also closely related to https://github.com/threeme3/usdx/blob/master/usdx.png.

Mapping table:

```
S              0    1    2    3    0    1    2    3
Pin           10   11   12   13   10   11   12   13

truSDX        -q   +I   -I   +q   -q   +I   -I   +q
```

Is this a valid ordering / configuration (it is not a "gray code" anymore though)? Thanks.

dawsonjon, 2024-06-18:
Hi,
I have taken a closer look and added some comments in-line. Your project sounds very interesting, best of luck :-)
Thanks
Jon

> From https://files.tapr.org/meetings/DCC_2020/2020DCC_KL7NA.pdf,
This is a very interesting article, I will have to take a closer look.

> ![Screenshot_2024-06-18_07-39-06](https://private-user-images.githubusercontent.com/79528/340511570-97215a63-4a74-4e71-afe0-c148d805467e.png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)

I'm a little bit confused by this table, reading the article it sounds like the "counting" method is a work around to allow the Si5351 to work at low frequencies and switches in the order 0, 1, 2, 3. I think the "quadrature" method  is the more usual method (employed by uSDX), where the device generates 2 clocks 90 degrees out of phase (i.e. in quadrature). The last line in the table says that the order is also 0, 1, 2, 3 but this seems to contradict the text and I think it might be a mistake.

> In my flavor of your `PicoRX` design, I am planning to use the quadrature clocks from Si5351, where the counting order seems to be 0, 1, 2, 3. The `truSDX` design uses quadrature clocks from Si5351 too. I am planning to use the quadrature clocks from Si5351 in hope of better RX performance.

Great, I think that the Si5351 should improve the Rx performance. The Si5351 allows much more precise programming of the frequency so it should be possible to reduce the bandwidth of the Tayloe detector. This means that the oversampling ratio will be higher and this should improve the rejection of alias signals.

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

I don't think this is a valid sequence, each step should rotate 90 degrees in the same direction. Moving from +I to -I or +Q to -Q is a 180 degree rotation. This suggests to me that the switching order in the truSDX isn't 0, 1, 2, 3. It would need to be either 0, 1, 3, 2 or 0, 2, 3, 1 to give a valid sequence.

Copying the truSDX is a safe option, it uses the Si5351 and we know it works. Worst case it will rotate in the opposite direction, but this can easily be fixed in software by swapping I and Q.  This latest test build of software allows I and Q to be swapped through the menu, so should be easy to try it both ways.

kholia, 2024-06-19:
I agree with you. With Si5351, the switching order has to be 0, 1, 3 ,2 too! There must be an error in that article.

Here  is my understanding based on a picture borrowed from https://awsh.org/si5351-quadrature/ link:

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

Initially, both 'waves' are off. This gives us 00. Next, one signal ('wave') rises up. This gives us 01. Next, both waves are up, this gives us 11. Finally, the initial waves goes down and this gives us 10. Next, we get 00 again and so on. So the clocking sequences is naturally 0, 1, 3, 2.

...

The design is public @ https://github.com/kholia/PicoRX/tree/master/PCB/Easy-uSDX-v3.

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

Note: I have provided jumpers to switch the 11 and 12 connections as needed. I can copy the truSDX design as well but perhaps going ahead with these four jumpers for the first version is a more easier decision.

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

The board size is 45mm by 45mm.

...

In my experiments, having a large bandwidth (open) creates problem as I live next to a 100 KW AM station (792 kHz), and there is also a powerful radar system operating very next to the 10m band. Hence, my desire to operate with a narrow bandwidth.

Thanks for all the help!

dawsonjon, 2024-06-20:
Sounds like a good way forward. That PCB looks really neat, would be interested to see how it turns out. Cheers, Jon

Closed 2024-08-09.

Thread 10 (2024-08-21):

using a different display?

wa2mze, 2024-08-21:
I found this display, https://www.aliexpress.us/item/3256806709509463.html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
which is larger than the one you are using.  However, it uses a different controller chip.   I wonder how difficult it would be to change the driver code for it?  Adafruit has an arduino library that should work, but you are using the SDK not Arduino.  Any ideas?

penfold42, 2024-08-22:
It claims to be compatible so if you buy the 4 pin I2C version it might just work.
The pictures show a default I2C address of 0x3c which is what this code expects

I was considering adding SH1106 support as i have one and they are 1.3" from memory, but maybe ill buy the one you linked.

dawsonjon, 2024-08-22:
Yes, I read that it was compatible, I wasn't sure if it meant electrically compatible or a drop replacement. For that price it might be worth a punt.

wa2mze, 2024-08-22:
There are two different displays that use the SH1106 and SH1116 chips, the 1.3" and 1.54"  I bought the larger one.  There is a web page out there that shows the differences between the various OLED controllers, the most important ones being in initialization (if done wrong the display won't even start or light up), and in addressing (the SH versions seem to have a max column address of 132 instead of 128 and also support only a single addressing mode).  It is possible to carve out a common feature set that will work with all of the controller versions.

MrSVCD, 2024-09-03:
Speaking of larger displays, I found these on ebay: https://www.ebay.com/itm/296119960051
SSD1309 should be compatible with SSD1306 but don't quot me on that. I only fund this on a Swedish sellers site.

bmentink, 2024-09-03:
> I found this display, https://www.aliexpress.us/item/3256806709509463.html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 which is larger than the one you are using. However, it uses a different controller chip. I wonder how difficult it would be to change the driver code for it? Adafruit has an arduino library that should work, but you are using the SDK not Arduino. Any ideas?

I can confirm that this display works perfectly with the latest build of the code. Now my old eyes can actually read the display :)

wa2mze, 2024-09-03:
I did a git pull and loaded the new .uf2 file for the pico1 and tried the display.  It lights, but only displays random junk on the screen.  I will need to play with the OLED driver, as mine doesn't work.  Some of the Chinese displays actually have a CH1116 controller, not an SSD1309 or SSD1306.  The CH1116 internally has a 132 wide column count, not 128, so the addressing may be off if compiled for the SSD variants.  The fix may be just to init for 132 X and 64 Y instead of 128 x 64 y.

bmentink, 2024-09-03:
Yep, I noticed the same on rp2040 but it works ok on the rp2350 . .. go
figure

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

penfold42, 2024-09-03:
> Yep, I noticed the same on rp2040 but it works ok on the rp2350 . .. go figure. Also note, mine has CH1116 marked on it, but still works fine on the rp2350 ..

You could try some pull up resistors on SCL and SDA if the display doesn't provide them.

When it works, do you configure it as ssd1306 or sh1106 ?
The init sequences are identical. when we write the data we just offset the starting address by 2 on the sh1106

bmentink, 2024-09-03:
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

I have not touched the code at all. It runs with the default, whatever that is. I have not needed any pull-ups either, maybe the rp2350 has internal pull-ups turned on?

wa2mze, 2024-09-03:
Don't know, I haven't recompiled anything, just used the pre built uf2 file.  I don't think I need the pull ups, I can see the display being updated, and it responds to changes in frequency, etc.   Just not readable because all the pixels are in the wrong place.

bmentink, 2024-09-03:
> Don't know, I haven't recompiled anything, just used the pre built uf2 file. I don't think I need the pull ups, I can see the display being updated, and it responds to changes in frequency, etc. Just not readable because all the pixels are in the wrong place.

Do you have a pico2 you can try?

wa2mze, 2024-09-03:
Don't have a pico2 yet.  I'm on the notify list at digikey and sparkfun for one.

bmentink, 2024-09-04:
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
Here it is ..

penfold42, 2024-09-04:
I _definitely_ need to find a better 2X font!

bmentink, 2024-09-06:
Just discovered that the riscv build works with pico2/CH1116 display combo perfectly, but the ARM build does not, just gives screen full of random pixels ..
I.E pico2rx-riscv.uf2  works, pico2rx.uf2 doesn't ...

dawsonjon, 2024-09-07:
Have you tried these builds? https://github.com/dawsonjon/PicoRX/actions/runs/10704854534

bmentink, 2024-09-10:
> Have you tried these builds? https://github.com/dawsonjon/PicoRX/actions/runs/10704854534

Is that question aimed at me? What has changed for those builds?

ThiagoDSP, 2024-10-02:
Has anyone tested this 2.42" screen? A 2x larger screen would be great. It seems to use the ssd1309 controller

https://a.aliexpress.com/_msi84Y0

mryndzionek, 2024-10-09:
Just refreshing the thread. On `testing` branch we are using u8g2 library, so many more displays should be supported. [Here](https://github.com/dawsonjon/PicoRX/blob/testing/ui.cpp#L3057) adjusting this `Setup` function should be all that's needed. The list of available setup functions: https://github.com/olikraus/u8g2/blob/master/csrc/u8g2.h#L680 (use the ones with `_f` at end).

penfold42, 2024-11-10:
> Has anyone tested this 2.42" screen? A 2x larger screen would be great. It seems to use the ssd1309 controller
>
> https://a.aliexpress.com/_msi84Y0

I just received https://www.aliexpress.com/item/1005006100836064.html - blue I2C in my case.
Looks the same as your link.

Works fine as a "ssd1306" in PicoRx.
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

It's comically large in comparison to the 1.3" SH1106 I replaced

spanglz, 2025-03-15:
Did anyone connect ST7567S display?

Like this:
https://aliexpress.ru/item/1005004252465006.html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

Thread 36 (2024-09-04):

PicoRX Breadboard values and questions.

MrSVCD, 2024-09-04:
I am planing to make a PicoRX-breadboard and I have a couple of questions:

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
Is this the correct values for the color codes?

Is the audio out stage correct? It is different from the schematic.

Can I use fst3253mtcx instead of 74CBTLV3253? [https://www.electrokit.com/en/fst3253mtcx-wtssop-16-dual-1-of-4-multiplexer](https://www.electrokit.com/en/fst3253mtcx-wtssop-16-dual-1-of-4-multiplexer)

dawsonjon, 2024-09-04:
> Is this the correct values for the color codes?
Yes

> Is the audio out stage correct? It is different from the schematic.
It should work either way round.

> Can I use fst3253mtcx instead of 74CBTLV3253? https://www.electrokit.com/en/fst3253mtcx-wtssop-16-dual-1-of-4-multiplexer
Yes, but its a 5v device so needs to be powered from 5v rather than 3.3v.

Best of Luck
Jon

penfold42, 2024-09-04:
There is 1 wire missing from the schematic - the rotary encoder's push button goes to GPIO 5

MrSVCD, 2024-09-05:
Can I replace 56nF to 68nF?

dawsonjon, 2024-09-05:
Yes, close enough👍

MrSVCD, 2024-09-05:
Parts have been ordered, I have a deadline of October 1 so hopefully I can get it built before then. https://arcticradio.net/schedule

MrSVCD, 2024-09-12:
Progress report on my build.
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

dawsonjon, 2024-09-12:
Nice! 👍

MrSVCD, 2024-09-13:
What does the buttons do?
Backstory: I am reusing a old slide image viewer as the base for my control panel and my rotary switch push button is quite stiff so the viewer moves around if i mount it on the side.

MrSVCD, 2024-09-13:
I now have a working radio! It is late here so I will test it more tomorrow.

penfold42, 2024-09-14:
> What does the buttons do? Backstory: I am reusing a old slide image viewer as the base for my control panel and my rotary switch push button is quite stiff so the viewer moves around if i mount it on the side.

The encoder push button is not (presently) required.
- in the home screen it jumps straight into Recall
- in the menus, doubles as the right (MENU) button

MrSVCD, 2024-09-14:
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
Accidental power supply, did not think it would work.

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
Complete radio.

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
So the next goal is to build the radio fully into this viewer since there is quite some space in it.

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

penfold42, 2024-09-15:
I love it!

I may have to get some toothpicks, blutak and 3 credit card size fresnel magnifiers....

MrSVCD, 2024-09-23:
I am now satisfied with my build. I received my first LW station so I very happy.

dawsonjon, 2024-09-23:
Cool, really pleased you got it working!

Closed 2024-09-23.

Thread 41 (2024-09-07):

Performance improvements suggestions

mryndzionek, 2024-09-07:
I've finally received the last components and build Tayloe detector. Assembled everything partisan style on a veroboard. It definitely works. Here is a sample recording:
[pico_rx_1.mp3.zip](https://github.com/user-attachments/files/16914856/pico_rx_1.mp3.zip)

There seems to be however a lot of noise everywhere. What can I do to improve this? Bandpass filters? Better antenna? Maybe some wires need to be shielded (LO_Q, LO_I?)?

penfold42, 2024-09-07:
Mines pretty crappy too but i've used even worse components:
- 74HC4051 and MCP6002 (rather than MCP6022).
- no preamp at all. But I have some high power AM broadcast towers nearby
- It might also have developed a defect. Swapping IQ no longer makes any difference!

Some possible causes of noise:
- Grounding is important - vero/donut/breadboard has no ground plane so its tricky to keep the noise down.
- separate analog/RF and digital VCC and GND connections.
- You might have some LO radiating into the amp if they're nearby.
- Do you have an LC band filter? My hack job has some provision for dropping these in.
- OLED charge pump noise. The TruSDX guys were modifying the oled so they could disable it IIRC

Tonytti, 2025-01-17:
To use band pass filter is a must. I build pico rx and i use an external preselector/band pass filter for any ham band. It works well, apart 40 meter at night due a strong Chinese broadcast station at about 7.250 who produces several intermodulation products, it's strange because tayloe detector should be a "bomb proof" mixer. Maybe LO is not very clean? I will investigate.

mryndzionek, 2025-01-17:
> an external preselector/band pass filter

Any details on this? DIY, or bought? I added a simple 30MHz low-pass which improved the situation a little bit. I also was experimenting with a very simple hand-tuned preselector, but it was too inconvenient to tune.

penfold42, 2025-01-17:
Could you breadboard some of the filters from the [PCB version](https://github.com/dawsonjon/PicoRX/blob/master/PCB/pico_rx/pipicorx.pdf) ?

dawsonjon, 2025-01-17:
@Tonytti

> It works well, apart 40 meter at night due a strong Chinese broadcast station at about 7.250 who produces several intermodulation products, it's strange because tayloe detector should be a "bomb proof" mixer. Maybe LO is not very clean?

Given that the interfering signal is within a few hundred kHz, I think what you are seeing here is ADC aliasing rather than intermodulation. if you have exact frequencies I can confirm, but there have been other reports. The Tayloe detector rolls off at about 12dB per decade, so a strong signal outside the Nyquist zone of the ADC might still get through. There is a very simple fix that can greatly improve the alias rejection, and that is to add a simple RC low pass filter between the op-amp and ADC. A 5.6k series resistor followed by a 1n capacitor (repeat this for the I and Q ADC inputs) works well.

As you say, the Tayloe detector is very robust to overloading and is mostly only sensitive to interfering signals at odd harmonics of the LO. For example, if you are working the 40m band, you might also see signals around 21MHz. That's where a preselector or band pass or low pass filter might help.

(Of course if you have an LNA, it will likely have a much lower IP3 than the Tayloe detector and you might see some IMD).

Tonytti, 2025-01-17:
Thanks a lot for your answer. I'll let you know...

Il giorno ven 17 gen 2025 alle 09:12 dawsonjon ***@***.***>
ha scritto:

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

Tonytti, 2025-01-17:
@mryndzionek
Adding a 30 Mhz low pass filter doesn't help. The simplest way is mounting lpf just as indicated on the reported schematic on git hub. For more severe filtering band pass filters are suggested for any band of interest. It is particularly important on ham bands where generally you deal with weak signals compared to the broadcast stations ones.

Tonytti, 2025-03-03:
...i bypassed all connections to oled display and now it is quite silent. An impedence and bog capacitor on 3.3 volt. Other two impedances on scl and sda. Now it's good

dawsonjon, 2025-03-03:
Cool, that's great 👍 I would be interested to know the details, what component value did you use?

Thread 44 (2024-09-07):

Allocate GPIOs for SPI/SDcard interface?

penfold42, 2024-09-07:
SPI1 on GPIO10,11,12,13 ?
and maybe GPIO 14 and 15 for additional SPI slave selects (or multiplexing via a HC139 ?)

dawsonjon, 2024-09-07:
I have been working on a ili9341 TFT waterfall, I've provisionally allocated allocated these pins.

    #define PIN_MISO 12
    #define PIN_CS   13
    #define PIN_SCK  14
    #define PIN_MOSI 15
    #define PIN_DC   11
    #define PIN_RST  10

Obviously, I'm not actually using the MISO pin, but thought it made sense to allocate it so that the SPI could be used with other peripherals such as SD card or similar. I will ditch the RST pin if I can, and might try to double up the DC pin with something else too if I can.  I would like to keep GPIO28 spare for a microphone input, and 3 other pins for TX functions. Perhaps we should allocate GPIO9 as SD card CS pin?

MrSVCD, 2024-09-09:
Since you are asking, what are your plans for the SD card?

penfold42, 2024-09-09:
@mryndzionek suggested sd card recording in the #15 features discussion issue

@dawsonjon re: PIN_CS on gpio 13 vs 9. Not sure there's much benefit one way or the other.
Are we rapidly running out of pins? :) I guess theres 3 options:
- a pico2 board with the bigger package
- layout a board with the bigger package on it
- use a I2C gpio expander for the slower speed stuff (buttons, but not encoder)

MrSVCD, 2024-09-13:
If you go the I2C expander route, you could "just" use another Pico. It is a bit more expensive than a MCP23017 but gives more options.

penfold42, 2024-09-14:
> If you go the I2C expander route, you could "just" use another Pico. It is a bit more expensive than a MCP23017 but gives more options.

Quad core radio :)

Beware the I2C MCP23017 - silicon bugs require A7 and B7 be set to outputs

mryndzionek, 2024-09-14:
What about the bandpass filter control pins (2, 3, 4)? The breadboard version doesn't use those pins.

penfold42, 2024-09-14:
Ideally the one firmware would work on both with no runtime config.

For best image rejection (and noise) you should really use the band select filters.

MrSVCD, 2024-09-15:
As I was looking for other ways to add buttons. Can ADC2 be used to add a keypad?
There is a way to add a keypad using a bunch of resistors.
Here is some maths and designs [Keypad.zip](https://github.com/user-attachments/files/17006558/Keypad.zip)
The only change to the circuit when the keyboard is not installed would be a 10k resistor from ADC2 to ground. The RP2350 has a currently a bug for the internal pull-down resistor and I don't know the value so a external one would be a safer bet.

dawsonjon, 2024-09-15:
I'm quite keen to keep the spare ADC input as a mic input when I add TX capability. It will probably double as a morse paddle input too.

Another option to consider is to add an IR remote. Only needs one IO pin... IR remotes are also very cheap, often cheaper than a keypad.

MrSVCD, 2024-09-19:
Since I am computer collector I have some Apple Desktop Bus stuff and it uses only one I/O pin. There is another signal in the standard that is only used for a remote power button.

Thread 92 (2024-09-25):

NE5532P opamp issue

mryndzionek, 2024-09-25:
I've tested NE5532P opamp. It's 10MHz bandwidth and noise density of 5 (at 1kHz), but it doesn't seem to be working. Recommended minimum supply voltage is 5V. I'm powering from USB, which after diode drop is 4.6V. Could this be the issue? Some sources claim that it operates from 3V.

dawsonjon, 2024-09-25:
I haven't tried it myself, but it's quite a popular option for this type of thing.  You could try a 5v power supply to eliminate the voltage drop as a possibility? Maybe power on Vbus rather than Vsys? What are the symptoms? Is the op-amp saturating or sitting around mid supply rail?

mryndzionek, 2024-09-25:
> I haven't tried it myself, but it's quite a popular option for this type of thing. You could try a 5v power supply to eliminate the voltage drop as a possibility? Maybe power on Vbus rather than Vsys? What are the symptoms? Is the op-amp saturating or sitting around mid supply rail?

The receiver shows extremely low signal, barely breaking S0 squelch on some frequencies. I also tried LM358P and it works! Just a little bit more noise than MCP6022. I think this is faulty chip. I'll have some more in few days, so I'll check then.

Closed 2024-09-26.

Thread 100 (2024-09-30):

Regarding SSB demodulation

bahari, 2024-09-30:
I noticed a major update in the new release code regarding LSB and USB demodulation. At which part on the latest code did you put the SSB modulation process?, there is a major update compared to previous code that I used. I'm in the middle try to understand your code design.

dawsonjon, 2024-09-30:
Sure, the most significant change is the move to FFT based filtering in the frequency domain. This method of filtering is inherently more efficient than filtering in the time domain and allows much sharper (brick wall) filters to be implemented without any significant increase in CPU usage.

Other benefits are that it is now possible to modify the filter bandwidth on the fly, and it opens up the possibility of other more dynamic frequency domain filtering such as the adaptive notch filter.

SSB demodulation also becomes much simpler under the new scheme. It is easy to suppress the unwanted sideband simply by removing either the positive or negative frequency bins (in effect making a complex filter with an asymmetric frequency response). Once the unwanted sideband is removed, the demodulation is a trivial matter of selecting either the real or imaginary component.

I will update the documentation, and probably do another video once the next batch of software updates are completed. In the meantime, let me know if you have any questions and I will be happy to help.

bahari, 2024-10-01:
Thanks for the information, I'm really appreciate it. Is it possible to improvise the code to include a noise ratio so that we can reduce the back ground noise? or is it any way to reduce the back ground noise,

dawsonjon, 2024-10-01:
I don't think there are any magic solutions to this, HF bands are inherently quite noisy due to atmospheric effects.
There are things that can be done to help, starting with the choice of antenna, using the best possible antenna setup will probably give the best improvement overall. Some antennas are more sensitive to noise than others, a horizontal dipole is less susceptible to noise than a vertical antenna, and directional antennas can be positioned to minimise noise.
It's also a good idea to minimise loss in the antenna feed line,   by using good quality cable and keeping the cable length as short as possible. Adding a low noise amplifier to the close to the antenna will also improve the overall noise performance too.
It's worth minimising any local sources of RFI, try unplugging things and see if the situation improves.
You could also try minimising PSU noise, add plenty of decoupling capacitors, and it's sometimes worth experimenting with their location.
In software, you can minimise background noise by using the narrowest possible bandwidth settings. It is also possible to implement noise reduction using spectral subtraction techniques. It's something I would like to implement, and that was part of the motivation for the frequency domain filtering. Its definitely something that I would like to look at!

bahari, 2024-10-02:
Basically I compare the receiving noise with my home brew USDX based radio with the same antenna setup. For my existing home brew rig the background noise are not as much as the Pico radio. One more thing, regarding RX gain calibration in the HW config menu, it is only to calibrate the base value for signal strength and spectrum measurements right?

penfold42, 2024-10-02:
> One more thing, regarding RX gain calibration in the HW config menu, it is only to calibrate the base value for signal strength and spectrum measurements right?

Yep

penfold42, 2024-10-02:
> Basically I compare the receiving noise with my home brew USDX based radio with the same antenna setup. For my existing home brew rig the background noise are not as much as the Pico radio.

Do they have the same front ends ? same mux, same opamp ?
It would be an interesting comparison to use the frontend from the USDX with the pico

bahari, 2024-10-02:
> Do they have the same front ends ? same mux, same opamp ? It would be an interesting comparison to use the frontend from the USDX with the pico

For PicoRX, I'm using the same components for Tayloe detector used by my (USDX) home brew rig. The difference only on LPF part, for my PicoRX I'm only implements 0-30MHz LPF, but with my USDX there is a pre-LPF for each bands of interest plus final LPF for TX second harmonics suppression. Later I will shared my setup picture.

dawsonjon, 2024-10-02:
I wonder if the usdx values might give a bandwidth that is too narrow? I think that 82k and 1nF give a bandwidth of about 2kHz, but the Pico Rx uses an IF of 6kHz?

Still very keen to add the transmit capability, watch this space!

bahari, 2024-10-04:
> I wonder if the usdx values might give a bandwidth that is too narrow? I think that 82k and 1nF give a bandwidth of about 2kHz, but the Pico Rx uses an IF of 6kHz?
>
> Still very keen to add the transmit capability, watch this space!

Yes you're correct USDX Tayloe detector bandwidth are set at approximately 2kHz. If I'm not mistaken PicoRX the first version are set to 12kHz and not 6kHz, correct me if I'm wrong

penfold42, 2024-10-04:
The pdf schematic at https://github.com/dawsonjon/PicoRX/blob/master/PCB/pico_rx/pipicorx.pdf shows 15n caps which should give a QSD cutoff of 45kHz

The breadboard at https://101-things.readthedocs.io/en/latest/_images/breadboard_radio_schematic.svg shows 56n caps at states 12kHz.

dawsonjon, 2024-10-04:
I'm currently using about 12kHz bandwidth in the Tayloe detector. The Pico Rx uses a low-IF frequency, the local oscillator is tuned 6kHz either side of the dial frequency (or as close as possible). This means that the wanted signal ends up at + or -6kHz, this is then shifted back to the centre in software. This really helps remove all the noise and interference around DC.

The 2kHz bandwidth detector that's used in the USDX is too narrow to work well with the picorx, the wanted signal at +/-6kHz will be outside the passband of the detector and will be significantly attenuated.

bahari, 2024-10-04:
> I'm currently using about 12kHz bandwidth in the Tayloe detector. The Pico Rx uses a low-IF frequency, the local oscillator is tuned 6kHz either side of the dial frequency (or as close as possible). This means that the wanted signal ends up at + or -6kHz, this is then shifted back to the centre in software. This really helps remove all the noise and interference around DC.
>
> The 2kHz bandwidth detector that's used in the USDX is too narrow to work well with the picorx, the wanted signal at +/-6kHz will be outside the passband of the detector and will be significantly attenuated.

Understood @dawsonjon, I misunderstood regarding 6kHz IF frequency implementations. No wonder when I increasing the Tayloe Detector bandwidth to 12kHz the reception are far more better compared to 2kHz bandwidth. Is it ok to maintain the same feedback resistor and capacitor as a gain control for the preamplifier? same as USDX?

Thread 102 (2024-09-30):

Distortion question

mryndzionek, 2024-09-30:
I'm attaching a sample wav:
[distortion.wav.zip](https://github.com/user-attachments/files/17190594/distortion.wav.zip)

There is this strange distortion, like wind blowing on a microphone. Is this a sign of something getting overloaded?

dawsonjon, 2024-09-30:
Does it only happen with very strong signals? I haven't allowed for worst case growth in the FFT, but instead chose a scaling that seemed to avoid overflow even for strong stations (that saturate the op-amps). It's possible that there might still be some overflow with very strong stations. To check, you could try setting extra-bits to zero, this should avoid overflow even for worst case scenario.

dawsonjon, 2024-09-30:
Fair enough, I tend to find that interference from the oled display tends
to worsen at higher frequencies, does it make any difference when the
display is disabled? It couldn't hurt to try a broadcast FM trap if you
have one, the Tayloe Detector is sensitive to interference at odd
harmonics, and the 7th/9th harmonic would sit in the broadcast FM band at
this frequency range.

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

mryndzionek, 2024-09-30:
> Fair enough, I tend to find that interference from the oled display tends to worsen at higher frequencies, does it make any difference when the display is disabled? It couldn't hurt to try a broadcast FM trap if you have one, the Tayloe Detector is sensitive to interference at odd harmonics, and the 7th/9th harmonic would sit in the broadcast FM band at this frequency range.
> […](#)
> On Mon, 30 Sep 2024, 15:50 mryndzionek, ***@***.***> wrote: AGC - not much difference, extra-bits also. It happens on fairly strong signals (S7-S9), but seems to randomly go away. It's also on frequencies above 10-13MHz. Sometimes it sounds like a different voice "trying" to come through. I wonder if it's some FM 88-108 interference. — Reply to this email directly, view it on GitHub <[#102 (comment)](https://github.com/dawsonjon/PicoRX/issues/102#issuecomment-2383428938)>, or unsubscribe <https://github.com/notifications/unsubscribe-auth/AAFPFX6W4ZZZXZKP3P5A7LLZZFQIJAVCNFSM6AAAAABPDJTKOWVHI2DSMVQWIX3LMV43OSLTON2WKQ3PNVWWK3TUHMZDGOBTGQZDQOJTHA> . You are receiving this because you commented.Message ID: ***@***.***>

Now it has gone away and the sound is very good. Actually I am using a FM trap, but DIY and unmeasured, so I don't know if it works :)

penfold42, 2024-10-02:
> Now it has gone away and the sound is very good. Actually I am using a FM trap, but DIY and unmeasured, so I don't know if it works :)

Was that after my PR which disabled I2C writes if the display is off?

Do you have the band LPF on the front end ?

mryndzionek, 2024-10-02:
> Was that after my PR which disabled I2C writes if the display is off?

It was before. At night some stations sound perfect. I have some strange local interference. I also put my LNA into a metal box.

> Do you have the band LPF on the front end ?

No, no LPF. Just a DIY FM trap.

penfold42, 2024-10-02:
Many AM transmitters lower their power at night - maybe try an attenuator during the day to see if that helps?
Which reminds me of one of my todo items - control an external attenuator like a pe4302.

I wonder how hard it would be to implement overload detection. At the ADC its easy - count # of samples that are too close to 0 or 3.3v but I'd like to detect clipping that could be introduced by the opamp too...
This would become super useful if i play with an external attenuator to to AGC on an LNA

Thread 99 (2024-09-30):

Show us your build !

penfold42, 2024-09-30:
No matter how modern, steampunked or deviated from the recommended design :)

I'll kick things off...
Mine has a few substitutions based on what was to hand:
TL072 for the opamp
74HC4052 scavenged from a Pace set top box :)
The four tayloe caps are 27nF cos the 74HC4052 has a higher Ron
Small proto area that I can use for band low pass filters (the green wire.
No preamp.

Its good for about 10MHz, FT8 on 14MHz is buried in noise.
Local AM stations are fine on an old skool wire loop antenna and some will totally overload the radio when on my EFHW.
The EFHW works well for 40m stuff.

Top view with SH1106 and buttons - the 2 boards could be folded back to back
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

Close up of the RF front end board
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

And some pretty average soldering...
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

dawsonjon, 2024-09-30:
Brilliant 👍 I love this stuff 😁

mryndzionek, 2024-09-30:
My first build was similar, but I fried some components while experimenting with random wire antenna and grounding. The second one is a little bit tidier :smile:

penfold42, 2024-09-30:
> My first build was similar, but I fried some components while experimenting with random wire antenna and grounding. The second one is a little bit tidier 😄

pictures or yours doesn't exist...

you dissen my neatness bro??
When I get around to ordering, ill probably just replace the RF board with the 3253 and an smd 6022 both on the green breakout.
At least it'll be mostly 2 dimensional

mryndzionek, 2024-09-30:
This is my current build. I run out of toner transfer paper, so had to draw it using a sharpie :face_exhaling:
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

dawsonjon, 2024-09-30:
Nice! Love the hand etched PCB 👍

MrSVCD, 2024-10-02:
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
My first build. It's needs 5v for the analog switch chip and I have had bad luck with power banks giving noisy output so I went with 6 ni-mh and a LDO linear regulator.
The next one is going to be a experiment in Manhattan PCB design.

dawsonjon, 2024-10-02:
Very neat!

bahari, 2024-10-07:
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
This is my projects setup. I'm adding RX amplifier and programmable step attenuator hardware. I'm also editing the existing code to include a menu for programmable step attenuator.

dawsonjon, 2024-10-07:
Very cool, really like the step attenuator. How are you controlling it?

JimReagans, 2024-10-07:
This is my2nd build of Jon's picoRX. I'm using a pico2 with an external Tayloe decoder which allows me to mess with filter parameters.
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
Cheers, Jim W0CHL

dawsonjon, 2024-10-07:
Nice work!

bahari, 2024-10-07:
> Very cool, really like the step attenuator. How are you controlling it?

Basically the relay controlling 3 attenuator base value which is 3, 5, and 10dB. From the combinations of this 3 value I can get an extra 10, 13 and 18dB. I'm adding 3 GPIO from Pico to control the relay via ULN2803. I modified your code with extra attenuator menu to select which attenuator value to used. This really help when I'm attaching my 20dB RX amplifier for strong signal attenuation process.

penfold42, 2024-10-07:
> > Very cool, really like the step attenuator. How are you controlling it?
>
> Basically the relay controlling 3 attenuator base value which is 3, 5, and 10dB. From the combinations of this 3 value I can get an extra 10, 13 and 18dB. I'm adding 3 GPIO from Pico to control the relay via ULN2803. I modified your code with extra attenuator menu to select which attenuator value to used. This really help when I'm attaching my 20dB RX amplifier for strong signal attenuation process.

Nicely done! Are you able to share your code?
Adding support for a PE4302 attenuator is on my list and it would be good to support multiple attenuator approaches.
I'll probably start with using 3 GPIOs to control the high order bits but move to I2C via a PCF8574

bahari, 2024-10-08:
> Nicely done! Are you able to share your code? Adding support for a PE4302 attenuator is on my list and it would be good to support multiple attenuator approaches. I'll probably start with using 3 GPIOs to control the high order bits but move to I2C via a PCF8574
Attached are the code. Effected code are ui.h, ui.cpp, rx.h and rx.cpp. Yeah using i2c is the right choice to control it.
[code-atten-cntrl.zip](https://github.com/user-attachments/files/17292027/code-atten-cntrl.zip)

penfold42, 2024-10-08:
> Attached are the code. Effected code are ui.h, ui.cpp, rx.h and rx.cpp. Yeah using i2c is the right choice to control it. [code-atten-cntrl.zip](https://github.com/user-attachments/files/17292027/code-atten-cntrl.zip)

Thanks! I got a shock when i diffed it against my working tree.
Then realised your code is based on master, not the testing branch where heaps of work has been happening lately! :)

bahari, 2024-10-08:
> > Attached are the code. Effected code are ui.h, ui.cpp, rx.h and rx.cpp. Yeah using i2c is the right choice to control it. [code-atten-cntrl.zip](https://github.com/user-attachments/files/17292027/code-atten-cntrl.zip)
>
> Thanks! I got a shock when i diffed it against my working tree. Then realised your code is based on master, not the testing branch where heaps of work has been happening lately! :)

Is there is any major update that improve the receiver performance on the testing branch?

MrSVCD, 2024-10-08:
> Basically the relay controlling 3 attenuator base value which is 3, 5, and 10dB. From the combinations of this 3 value I can get an extra 10, 13 and 18dB. I'm adding 3 GPIO from Pico to control the relay via ULN2803. I modified your code with extra attenuator menu to select which attenuator value to used. This really help when I'm attaching my 20dB RX amplifier for strong signal attenuation process.

How does one build a attenuator?
I don't really have any strong signals nearby but I am going on a vacation to a place should have stronger signals.

penfold42, 2024-10-08:
> > Basically the relay controlling 3 attenuator base value which is 3, 5, and 10dB. From the combinations of this 3 value I can get an extra 10, 13 and 18dB. I'm adding 3 GPIO from Pico to control the relay via ULN2803. I modified your code with extra attenuator menu to select which attenuator value to used. This really help when I'm attaching my 20dB RX amplifier for strong signal attenuation process.
>
> How does one build a attenuator? I don't really have any strong signals nearby but I am going on a vacation to a place should have stronger signals.

It can be as simple as 3 carefully chosen resistor values as described [here](https://www.electronics-tutorials.ws/attenuators/pi-pad-attenuator.html).
In @bahari design this is built on a relay that can switch them in or bypass them.
Then repeat this 2 more times with different values for different levels of attenuation.

You could just pre-build some plug in modules of fixed attenuation and manually plug them in

bahari, 2024-10-09:
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

It is based on PI attenuator topology. To calculate it  based on your need, please go to this calculator link: https://leleivre.com/rf_pipad.html

penfold42, 2024-10-19:
Finally got around to ordering better parts and built a new analog board.
74CBTLV3253 and MCP6022 as originally spec'd.

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
I've got enough room for an LNA but might need a 3rd board for band filters.

Performance is somewhat better based on a simple reported signal level using a TinySA as a signal generator.
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

Let me know if anyone wants me to do a comparison test of anything else before I recycle the old board...

MrSVCD, 2024-10-19:
Have you tried to battery powered your board? I have noticed that USB power is quite noisy. Might just affect my build since I use a 5v powered switch.
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
VK2ARH, 2025-02-02:
Glad you commented - than now makes more sense ... Indicated that there are likely to be more variants :) - I think the next iteration will look at disabling the incoming antenna signal when a Tx signal is detected to enable the unit to be used with 'companion transmitters'. Oh the fun continues.

bahari, 2025-02-09:
@dawsonjon I already pull your latest code and patch the code with my attenuator and RF switch (for filter selection) functionalities. I'm also integrate it with TFT screen and finally got the model which you previously suggested. The result was very good, very thanks to you and your team for a great improvements. 9M2GRC - 7 3

Video on 40m:

https://drive.google.com/file/d/1BPVP3ASSt92c-Rr9QGedGOUElRarHw4j/view?usp=sharing

Picture of my build:

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

bahari, 2025-02-09:
@dawsonjon One question, do you still maintain 12KHz (+6 and -6KHz) bandwidth on your Tayloe detector calculation? Correct me if I'm wrong, the RF spectrum bandwidth is it 30KHz?

dawsonjon, 2025-02-09:
@bahari Nice build! The Tayloe detector has a cutoff of +/-12kHz, and I use an IF of +6kHz or -6kHz. That means that the 3dB bandwidth is 24kHz and the spectrum displays 30kHz, so you can see the gain dropping off at the edges.

bahari, 2025-02-09:
@dawsonjon I noticed on the RF spectrum and it is consistent, in one occasion I can see there is RF detection at the positive side of the RF spectrum TFT screen, but when I  increase the frequency tuning, it is disappeared and the RF detection goes to the negative side of the display, do you observed the same?

dawsonjon, 2025-02-09:
Yes, that't because it chooses an IF of either +6 or -6kHz, the signal you
are seeing is noise around the NCO frequency/DC.

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

bahari, 2025-02-10:
@dawsonjon Today I also discovered there is RF detection on the positive side of the RF spectrum (around 18,000KHz ++), when I tuned it to the center, It's suddenly shifting to negative side of the display (near center) and I can hear the audio modulation. But when I tried to centered it, It suddenly disappeared and goes to positive end of the display.

wasshuber, 2025-02-19:
I find this a really cool use of a Pico. A quick question regarding the analog-switch/mux. The 74CBTLV3253 is suggested. Why would a CD4052 not be suitable? Too slow? R-on too high? I am wondering if there is a suitable replacement for the mux that is available in a DIP package.

penfold42, 2025-02-19:
> [...] Why would a CD4052 not be suitable? Too slow? R-on too high? I am wondering if there is a suitable replacement for the mux that is available in a DIP package. For example, why not a SN74LV4052AN or TC74HC4052APF?

Mostly because its too slow. Its higher R-on doesn't either.
Scroll up to my update from October with my [rebuild](https://github.com/dawsonjon/PicoRX/issues/99#issuecomment-2423709531)
I graphed the sensitivity before and after and you can see the HC4052 is useless beyond ~12MHz.
I also tried a CD4052 and its useless beyond ~1MHz.

I think you'll have to get comfortable with DIP/SMD adapters. They're cheap enough on ebay AliExpress and I see imsai_guy has produced some nicer looking skinnier boards for SOP packages on pcbway.

Frank-663, 2025-03-04:
@wasshuber

Instead of the 1:4 mux 4052 use a 4053 dual 1:2 mux as QSD

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

With the 1:4 mux, each switch is only one quarter of the period on and three quarters off.  With the 1:2 mux, each switch is on and off for half a period, which results in longer switch-on times. A 74HCT403 with +5V Vcc works up to at least 30MHz, some even up to 54MHz (6m). A 74HC4053 with +5V Vcc switches significantly slower with the (low voltage) TTL quadrature clocks of the RP2040.

Compared to a QSD with a 1:4 mux, the circuit with two 1:2 mux has a 2dB higher conversion loss. This can be compensated by using instrumentation amplifiers for the baseband signal instead of simple differential amplifiers.

wasshuber, 2025-03-04:
@Frank-663 Thanks. This is an interesting alternative. I appreciate it.

SyncChannel, 2025-03-08:
I made an SMD version of the PicoRX. The PCB size is the same as the Pi Pico, so it has a very small footprint. All of the digital circuitry is on the bottom side of the PCB (it's pretty packed down there). The top side includes a 7th order Chebyshev low pass filter with a cutoff at 30 MHz. There is a header for connecting a headphone jack to listen to the audio. Four layer board. It makes for a
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

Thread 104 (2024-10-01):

Bumping CPU clock

mryndzionek, 2024-10-01:
We are slowly climbing towards 100% of DSP core load. I think we should consider overclocking. Been experimenting with this some time ago and it seems we can safely bump the frequency by 100MHz. I was testing the range 225MHz to 255MHz. Only few milliamps increased current consumption.

mryndzionek, 2024-10-01:
> pico or pico 2 ?
>
pico

> Is the cpu clk separate from the PIO running the NCO ?

It's not separate, but I think the `clock.py` script can handle it, i.e. compute the right dividers. The accuracy doesn't look worse.

dawsonjon, 2024-10-01:
Cool, it's really good to know that we can successfully overclock by so much. Its certainly something that we should keep in mind for the future. I know that the pi-pico is known for its ability to be overclocked, but it is highly desirable to stay within the manufacturer's specification which will take variations in temperature and manufacturing process into account. This might be important if the code was ever used in a commercial product for example. I'm keen to avoid overclocking if we can help it, and would much rather look for opportunities to simplify the code if at all possible.

MrSVCD, 2024-10-01:
Is there any possibility to split the workload in half (or 1/3+2/3)?
And if it is possible: Since it is a receiver (so far) a small buffer causing a delay would not be fatal. This would allow the UX core do some of the work without the real time need that the current DSP core have.

I am just guy guessing here since I am a happy user.

On the other hand: If you want to make a commercial product out of this, the RP2354a/b would be a good choice since it has the flash built in like "normal" micro controller.

dawsonjon, 2024-10-01:
I don't think it's quite as bad as it looks, and there is still lots of potential to add new features.

The x32 decimation really helps, and adding code after the decimation doesn't have a huge impact on CPU usage. There is also potential to decimate by a further factor of 2 either before or after the modulation depending on the mode, which might be useful if we wanted to do some more sophisticated audio processing.

We can also get a massive speed up by filtering in the frequency domain, rather than the time wherever possible, and I think there is potential to further exploit this.

Transmit functionality shouldn't cause too many problems either, because we can disable the receiver when transmitting, the same would be true for features like audio playback.

There may well come a point where we can't fit all the functionality in a Pico (I'm thinking things like FT8 decoding). At this point it would probably make sense to make an enhanced pico2 version with extra features, we will probably need the extra flash and RAM too.

I don't have any specific plans for a commercial product, but a kit version based on a pi pico is frequently requested...

wasshuber, 2025-05-21:
I would be interested in producing a kit for the miniTesla solderless system. I have just posted a photo of the first test build. Everything seems to be working. A lot more experimentation will be necessary, but a kit with all the necessary components and nice instructions, including a detailed explanation of the software, would be the goal so that folks can experiment on both the hardware and software sides. I was thinking that this could even be the core project for a beginner electronics course. First, build picoRX in its simplest form and have the student experience the joy of receiving radio signals with a self-built circuit. Then go into the details, op-amp, detector, A2D, digital side, and then offer a few improvements for follow-up projects. Along the way, the student will learn some analog electronics, digital electronics, telecommunication, programming the Pico, ...

dawsonjon, 2025-05-22:
@wasshuber Sounds like a great idea to me! Your build is very reminiscent of my first experiments in radio and electronics, which inspired me to start a career in electronics. I think your kit would provide a very similar experience, but with a sleek modern feel. Best of luck!

wasshuber, 2025-05-22:
Thank you for the encouragement. Capturing that magic of experiencing radio reception with a DIY kit is exactly the goal. I experienced this myself, too, when I was 10 years old, building a radio with a Philips kit, having no idea about electronics, but miraculously achieving radio reception by following the build instructions. That is why I really like your picoRX design. It is indeed a modern version of the old diode and transistor receivers. Doing a kit without soldering extends it to a larger group of potential students. The main issue with radio kits is making them reliably replicable by a beginner without sophisticated testing and measuring equipment. So everything needs to be as stable and with large error margins as possible.

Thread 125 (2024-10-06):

Problem with USB audio streaming from core0

mryndzionek, 2024-10-06:
After moving the USB streaming to core0 the problem with mismatch of samplerates seems to be much worse then when streaming directly from core1. First of all I had to decrease the timer task rate from 500us to 250us and increase the ring buffer size, but even then the ring buffer occupancy grows steadily and after a while we're overwriting samples. I tried to measure the mismatch, but it seems it varies with the tuned receive frequency. An adaptive control of rate will probably be needed.

dawsonjon, 2024-10-07:
It is possible to get exactly 15 or 16 kHz. Changing the ADC clock divider to 100 gives an ADC sample rate of 480kHz. This gives exactly 15 kHz with the current decimation of 32 and a slightly reduced CPU loading. Reducing decimation to 30 gives exactly 16KHz but the ADC block size then needs to be reduced to 1920 and the CPU loading is slightly higher.

I think that there will still be some mismatch despite this since clock on the data sink will always be slightly different than the data source, but presume that the USB stack is designed to handle this.

mryndzionek, 2024-10-07:
I managed to implement a PI controller, but the results were still not that good - a lot a wiggle in the weatherfax. I tried switching to 15k samplerate and this seems to be giving good results. PR will land tomorrow.

mryndzionek, 2024-10-08:
Switched to 15k audio in #128.

Closed 2024-10-08.

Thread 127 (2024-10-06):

External down converter support ?

penfold42, 2024-10-06:
Is there any interest in supporting an external down converter ?

I suspect there's 3 levels of "support" we could do

1) configurable frequency offset in the UI
IF inversion to support low side and high side mixing

2) flip LSB and USB if required

3) Control of an external 1st IF
Si5351 over I2C
A separate NCO output

dawsonjon, 2024-10-07:
This is a cool idea. Using an SI5351 would certainly simplify things. You could then tune the Tayloe detector to a fixed frequency that is an exact division of the clock frequency. I'm almost tempted to say that this should be a project in its own right, would be very cool to build a general coverage receiver that goes up to VHF, and it would still be relatively simple.

MrSVCD, 2024-10-07:
One of the things that got me excited about this project is the low component count and the components that you need are quite easy to source aka "a crystal radio for today"
So I say add it as a option but keep supporting the original desig and have fun.

letonton, 2024-12-01:
On GitHub there are Pico libs for si5351 (ex. one by user "kholia").
Additionally we can use Analog ADF435x to reach 70 cm and beyond, SPi
Interface (ex. lib by '"davecrump" also on GitHub)
I agree about a new project thread.

dawsonjon, 2024-12-01:
Yes, I know at least one person has reported success recieving 2m and 70cm using external oscillator and mixer.  I would definitely like to try this sometime.

Maurmari, 2024-12-16:
Mister Kholia's Sî5351 routines work fine, but when I tried to integrate them
into PicoRx I got "undefined reference" errors... the issue is from mix c and c++
codes ? (Frankly I'm a big noob in c !)

dawsonjon, 2024-12-16:
Is it just a matter of using extern "C" {#include "xyz"}?

Maurmari, 2024-12-16:
I am a bit confused about that...

letonton, 2025-01-01:
Someone may help about the matter (compile Sî5351 support into picorx code ) ?

dawsonjon, 2025-01-01:
Sure, happy to help, can you give me some more details?

letonton, 2025-01-01:
Well, like "maurmari" I tried "kholia" code (I work in Win under Visual Studio).
Original code compiles nice, but when I try to add the files to picorx I receive
too a crowd of error messages like undefined reference to the functions.

letonton, 2025-01-01:
Nedless to say, I'm quite a newbie about c/c++ !

dawsonjon, 2025-01-01:
This one?
https://github.com/kholia/Si5351-Pi-Pico/blob/master/main.c

I don't use visual studio, but it should just be a matter of adding the .c file to the CMakelist.txt.

```
  add_executable(picorx
      ...
      si5351.c
  )
```

It has already been mentioned that the si5351 library is written in C, whereas PiPicoRx is written in C++.  If you call C code from C++ code you need to wrap the function declarations in an extern "C" {} declaration. This tells the compiler/linker that it is calling a C function rather than a C++ function. You can either add this to si5351.h (I did this in with the SSD1306 library, so you could use this as a template.  https://github.com/dawsonjon/PicoRX/blob/master/ssd1306.h#L36 ). Alternatively you can add the declaration when you include the file like this:

```
extern "C" {
#include <si5351.h>
}
```
Hope this helps. Cheers Jon

letonton, 2025-01-01:
Bingo ! Thank you very much for the tips.

badwolf3001, 2025-02-08:
Hello, everyone!

I haven't set up my circuit yet, but I'm considering having an option to include a tv tuner as a downconverter (probably with a bypass circuit). The IF output of a tv tuner is usually between 36 and 39 MHz (take 37 MHz as an average). The passband is usually 4 MHz. I believe it will be necessary to mix this output so that it is within the receiver's range (perhaps between 15 and 20 MHz). The frequency control of some tv tuners is controlled via I2C, which would facilitate possible integration. Do you think this approach is feasible?

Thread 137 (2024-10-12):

External I2C connector for peripherals.

MrSVCD, 2024-10-12:
I have thought about making a standard, of the de-facto kind, for external I2C devices to be used with PicoRX. My proposal is here: [https://github.com/MrSVCD/PicoRX-accessories/tree/main/I2C](https://github.com/MrSVCD/PicoRX-accessories/tree/main/I2C) and it is very much in the alpha phase of writing.

Examples of peripherals would be a keypad for entering frequencies or a full remote control panel like some ham radios have.

One thing that would stop this in its tracks is the speed of the I2C bus used with the display since I was thinking of reusing it and if it is too fast it would not be able to be reused because of cable length and signal degradation. This might not be a problem since I suspect that the cable length will not be longer that 2 meters in total.

In the proposal I am writing about using one pin for interrupts so that the pico don't need to poll the I2C bus constantly and can update the display without slowdown.

(Some of you might see the similarity to SOA standard that hack-a-day likes and that is what it is with modifications for PicoRX use.)

penfold42, 2024-10-13:
We could use a separate I2C bus for the lower speed stuff.
- buttons
- band filter selectors
- attenuators
- downmixers (eg Si5351)

MrSVCD, 2024-10-13:
I am asking since in issue #44 there was talk about adding a SPI port and in that discussion there was talk about using GPIO09 for Chip Select for a SD card and that would block I2C0 and I presume here that I2C1 on GPIO06-07 is busy being used on GPIO20-21 for the screen (but I don't know if that is how it works).

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

This is what I propose as a connector (IDC) and pinout. It is based on the rebelliously  *shitty add on 1.69bis* "standard" for conference badges. The difference is that the two GPIO pins have the definitions of INTerrupt and PWR?. I don't know what PWR? is yet and might turn into another GND or a NC.

dawsonjon, 2024-10-13:
That sounds about right. Since we are getting a bit short on io, I would suggest that the best option would be if peripherals shared i2c1 bus with the display. I think we could add low bandwidth peripherals like keypads without slowing the display too much.

MrSVCD, 2024-10-13:
@dawsonjon at what frequency is the display bus set at? 100kHz? 400kHz? more?

dawsonjon, 2024-10-13:
400kHz.

MrSVCD, 2024-10-13:
That is true, I didn't think of that. I have some cable laying around so I am going to do a distance test with a display. I will be happy if it works over 5 meters but I think 2 meters will be enough for most people.

@dawsonjon do you think that the pico should be polling or work on interrupt basis? It would require a extra pin but it would lower the load on the ui core. (And if using the display I2C works it would not interrupt the display update.)

penfold42, 2024-10-13:
If you're looking for metres of distance, I wouldnt use I2C - I'd recommend using USB (Serial).
It's shielded and uses differential signalling so will cause much less EMI and interference to the radio.

The PicoRX is already a USB serial "device" so you could easily hang it off a bigger Raspberry Pi.
This depends on implementing a CAT style serial interface for control and status which is already on the list.
With the USB Audio streaming thats nearly complete you also get the audio at your controlling RPi.

MrSVCD, 2024-10-15:
I have to admit defeat on external use of the I2C bus. While there exists solutions [https://www.adafruit.com/product/4756](https://www.adafruit.com/product/4756), I think it's is better and cheaper option to use a second Pico, and for my needs, a USB keyboard/keypad. Then you get plenty of i/o to control attenuation, amplifier etc.

Closed 2024-10-17.

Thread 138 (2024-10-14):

List of Alternative Parts?

UtopianElectronics, 2024-10-14:
Hi everyone,

I'm really interested in building this project, but I don’t have much knowledge about electronics/RF, so choosing alternative parts has been confusing, especially since some ICs aren’t available in my local market. Could you kindly provide a list of compatible alternative parts? Also, if using these alternatives requires changes to components like capacitors or resistors, could you let me know what modifications are needed?

Additionally, do I need to have a YouLoop antenna, a preamp, and a wideband LNA? I’m mainly looking to listen to shortwave radio stations right now, so is there a makeshift antenna or a very cheap option that could work for this?

I’d appreciate it if you could also confirm if these recommendations from ChatGPT are correct:

**For the Op-Amp:**
- High Noise Sensitivity: MCP6022, AD8602, NE5532, OPA2330, OPA2228.
- Low-Cost Designs: LM358, LMV358, TL072, TLV2372.
- Low Power/Battery-Powered: TLC272, TLV2372, LMV358, OPA171, OPA2244.

**For the Analog Multiplexer:**
- High-Speed/High-Performance: MAX4619, MAX4785, TS5A23159, MAX4617, TS3A5017.
- Low-Cost General-Purpose: CD4052, DG409, 74HC4052, SN74LV4052A.
- Low ON Resistance: TS5A23159, MAX4785, TS3A5017 (all under 1Ω).
- Low Power Consumption: SN74LV4052A, TS5A23159.

Someone on Reddit also mentioned using an SN74CB3Q3253 for the multiplexer. Could you please confirm this too?

Lastly, if possible, could you give me a list of key specs for any part so that I can show them to a shop owner to help me find alternatives that match the requirements?

Thanks so much!

penfold42, 2024-10-14:
The TL072 and MCP6002 (not the recommended 6022) do work, but their GBP is much lower than the recommended. MCP6022 so U guess you'll lose some of the higher ends of the downconverted signal.

The CD4052 is only good to about 1MHz and the 74HC4052 is ok to about 10MHz.
Their switching speeds are slower which is the limiting factor.
They also have higher Ron values so you should re-calculate the values of C10,11,12,13 using the formula in the schematic.
In my case with the HC4052 and an Ron of 70 ohms I calculated 27nF

mryndzionek, 2024-10-14:
Regarding opamps, if price is the main concern, choose a 5V one. NE5532P should work and is cheap and popular. I tried LM358P and it works with just a some audible degradation.

> do I need to have a YouLoop antenna, a preamp, and a wideband LNA?

From my experience I would say definitely yes. YouLoop gives weak signal, so LNA is necessary.

dawsonjon, 2024-10-14:
There is a bit of info on op-amp selection here: https://101-things.readthedocs.io/en/latest/breadboard_radio.html#operational-amplifier-alternatives. Basically you need less than 8nV/sqrt(Hz) noise voltage density and better than 10MHz gain bandwidth product. If you are using an LNA you could get away with a lower spec.

For the analog mux the on resistance and switching time are the key specs. The 74cbtlv3253 has an on resistance of 5 ohms and a switching time of 5.5ns. Something in this region would be ideal.

I can recommend the You-loop and LNA, have had good results using this setup. If you want a cheap antenna option, a DIY You-loop can be made from a loop of coax cable and a ferrite core transformer.

mryndzionek, 2024-10-14:
> For the analog mux the on resistance and switching time are the key specs. The 74cbtlv3253 has an on resistance of 5 ohms and a switching time of 5.5ns. Something in this region would be ideal.

So SN74CB3Q3253 is also good - Ron=4ohm and switching times 5.9ns (max).

penfold42, 2024-10-15:
Be careful if you use 5v Op-amps !

The pico is a 3v3 device so you'll need a resistive divider to drop its 5v output to 3v3

mryndzionek, 2024-10-15:
> The pico is a 3v3 device so you'll need a resistive divider to drop its 5v output to 3v3

Maybe it would be good to show the exact schematic. I guess it's a biasing circuit, right? A 100nf capacitor in series + a 50/50 divider connected to 3.3V.

UtopianElectronics, 2024-10-15:
Thank you. I already have LM324N and LM358N chips lying around from years ago. I’m guessing the LM324N doesn’t meet the required specs, but would the LM358N work well enough? I can’t find any LNAs here, except for a module marketed as "NRF24L01+PA+LNA," which seems to have an LNA chip onboard. Is there any way I could manage without an LNA, or possibly even without using a YouLoop antenna altogether?

mryndzionek, 2024-10-15:
>  but would the LM358N work well enough?

For listening to "commercial" AM stations with fairly strong signals should be okay. You can always use DIL/DIP connector and test different opamps later, as you can get them.

> I could manage without an LNA, or possibly even without using a YouLoop antenna altogether?

If you live in a /RF quiet/rural/ environment you can use a ordinary wire antenna. The signal will be stronger. I live in a noisy environment and don't have space for a wire antenna and magnetic antennas (like youloop) ale the only option. MMIC LNA's, often old and obsolete, can be found in shops for little money. You can also look into building an active loop with a simple transistor amplifier, like https://www.pa1m.nl/simple-active-receive-loop/.

UtopianElectronics, 2024-10-16:
> You can also look into building an active loop with a simple transistor amplifier, like https://www.pa1m.nl/simple-active-receive-loop/.

Still doing some research... I live in an isolated country at risk of war, so I’m trying to build this to receive SW radio for listening to news stations abroad, in case our electricity infrastructure gets hit. There’s no access to international financial/postal services here, so I can’t order an LNA from abroad, and even if I could, they’d be extremely expensive.

I live in a city and need a small, portable antenna I can move around with. The active loop with a simple transistor amplifier you linked needs 12V to operate, right? For now, I just need something basic for receiving MW/SW stations between 1.5 MHz and 18 MHz (In case you’re wondering why I’m not just building a SW receiver, I couldn’t find variable capacitors, toroids, etc. either.) Is there any way to compensate for the lack of an LNA and a You Loop antenna? What about using a coil-loaded antenna?

mryndzionek, 2024-10-16:
> What about using a coil-loaded antenna?

I guess it's hard to say without trying. In my experience YouLoop behaves very well in presence of noise. If there is not much noise than other antennas might perform better. If you're interested in specific stations/frequencies than a tuned magnetic loop might be good. See [here](https://www.youtube.com/watch?v=jlLj6hvG-2c). Here is a link to calculator - https://miguelvaca.github.io/vk3cpu/magloop.html . You can roughly see how many turns and what diameter covers which frequencies.

UtopianElectronics, 2024-10-18:
I’m not sure if I can complete this project due to the lack of RF parts here, but I do have some common equipment for receiving satellite TV, including a few LNBs and a receiver box. Is there anything inside them I could salvage that might be useful for this project?

penfold42, 2024-10-19:
You might be able to grab the RF front end from a 27Mhz CB radio or a 1980s shortwave radio.
The 74HC4052 I was using came from the tuner board of a pace set top box.
Most of the satellite stuff will have parts designed for frequencies much higher than HF

yasin112358, 2024-12-14:
what about miniwhip antenna does anyone used it?

Tonytti, 2025-02-28:
I've done a test with 74hct4053 and it runs beautifuly

mryndzionek, 2025-04-29:
Has anyone tested the following opamps?
TLC082
MC33078
TS522IDT
LM833
NJM4580

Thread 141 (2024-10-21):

Loop antenna build questions

MrSVCD, 2024-10-21:
I am looking to build a active loop antenna [https://www.pa1m.nl/simple-active-receive-loop/](https://www.pa1m.nl/simple-active-receive-loop/) and I have some questions:

1. Can I use steel for the loop instead of aluminum?
2. Can I use a FT-50A-43 core instead of a FT37-43? [https://www.electrokit.com/en/ferritkarna-ft-50a-43-7.2mm](https://www.electrokit.com/en/ferritkarna-ft-50a-43-7.2mm)
3. Can I use 9v instead of 12V?

Schematic for those that don't like following links:

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

penfold42, 2024-10-22:
I'm no expert but some thoughts come to mind:

>     1. Can I use steel for the loop instead of aluminum?
Google doesnt seem too positive on steel. lower conductivity, heavier (and rustier!)

>     2. Can I use a FT-50A-43 core instead of a FT37-43? https://www.electrokit.com/en/ferritkarna-ft-50a-43-7.2mm
You might need to adjust the number of turns if the inductance is critical

>     3. Can I use 9v instead of 12V?
You'll lose some gain and might also have to adjust the bias resistors

MrSVCD, 2024-10-22:
I found aluminium locally so that is no longer a problem. A hardware store for building had it as part of the tile accessories.

MrSVCD, 2024-11-02:
I have now made the amplifier and purchased a aluminum strip.
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
There is a high possibility that my transformer doesn't work but I wanted to try if it works with cat 6.

penfold42, 2024-11-02:
The links to images dont work either! :)

MrSVCD, 2024-11-02:
@penfold42 The latest jpeg encoding tricks in the gnu imp did not work.

MrSVCD, 2024-11-02:
It works! And it has better reception than my wire antenna.
Pictures of the success will come tomorrow.

MrSVCD, 2024-11-03:
Pictures as prommised:
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

Here is a video of me turning the antenna back and forth to show of the directionality of the antenna: [RadioTest-640.webm](https://github.com/user-attachments/assets/a6cc77d9-710a-46ea-b00c-a3165e0f1bd1)

Ps. This is inside a metal clad house, so it is going to be better when I get it outside.

dawsonjon, 2024-11-03:
Nice, really neat looking antenna, thanks for sharing!

penfold42, 2024-11-03:
Nice work!

Closed 2024-11-03.

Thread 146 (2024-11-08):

Attenuator design

MrSVCD, 2024-11-08:
I am trying to make a attenuator box but I am a bit stumped on getting the correct values unless I use trim pots.
Is this good enough?
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

I just realized as I am writing this that I only need 5dB, 10dB, 20dB so it is not that expensive to buy trim pots. So what I am asking if I should build it that way.

penfold42, 2024-11-09:
Too funny - was looking at a pi calc website last night - in my case for the downconverter I want to play with.
You can combine resistors in series or parallel to get the target values. I too cant seem to find my 17.615 ohm resistors...
The other option is just pick value that are close enough - I doubt you'd be able to hear or measure any real difference.

Can I interest you in a PE4302 that's on my list to add support for?
It just take a 6 bit binary input to select from 0.5 to 31.5 dB attenuation.
$5 and a single wire would let manually you select 0.5, 1, 2, 4, 8, 16 dB
two wires gets you some combinations - 8+16 = 24dB

MrSVCD, 2024-11-09:
Found the page for the replacement IC [https://www.psemi.com/products/rf-attenuators/general-purpose-rf-digital-step-attenuators/pe4312/](https://www.psemi.com/products/rf-attenuators/general-purpose-rf-digital-step-attenuators/pe4312/)

And also I found EU listing for PE4302 on ebay. 3v supply is going to be a challenge... * Reading data sheet * It is not going to be a problem since CR2032 exist and it draws 0.1mA.

MrSVCD, 2024-11-09:
> As for integration with Pi Pico - My plan is to couple it with a LCD I2C backpack so we can use I2C to set the pins

I was a bit confused what you meant but you mean a add-on board for a parallel LCD so it can be used with I2C like this one: [https://www.electrokit.com/en/i2c-interface-for-lcd](https://www.electrokit.com/en/i2c-interface-for-lcd) (They have also this one: [https://www.electrokit.com/en/i/o-expander-8-kanal-i2c](https://www.electrokit.com/en/i/o-expander-8-kanal-i2c) which uses the same IC)

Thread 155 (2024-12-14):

noise and background sounds

yasin112358, 2024-12-14:
ı have finally made my picorx but the noise and background sounds are really high ı did not use band pass filter and ı used miniwhip antenna in stead of dipol. can you suggest anything about it what would be the problem?

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

https://github.com/user-attachments/assets/4cc801f4-f224-4623-b202-15146dc0856f

dawsonjon, 2024-12-15:
Hi,
Build looks good, I particularly like the neat wiring that always turns at right angles.

With regards to noise there are a few possibilities.

The HF bands a generally quite noisy, so its informative to compare the noise level with and without the antenna connected. Ideally, the noise floor as indicated by the spectrum scope/s_meter should increase slightly when connecting the antenna. If it does, that's good news! It means that noise from antenna is larger than any internally generated noise within the receiver, and the antenna noise is large enough for the ADC to see. A Low Noise Amplifier can help with this, I find that combining an LNA with a You-Loop antenna gives pretty good results. I haven't tried the mini-whip, but I assume that it includes an LNA.

Sometimes external noise sources can have a negative impact on the receiver performance, its worth trying to switch off electrical appliances to eliminate them as a source of interference.

Both the TFT and OLED display can generate quite a bit of noise, its worth trying to disable them by setting the "timeout" in the HW menu. I haven't been able to completely remove the display noise, but it can be improved by careful layout. You might see some improvement by adding a ferrite bead to the display connections.

There can be some noise from the PSU too. Using series inductors and parallel capacitors can help with this (I see you have these). Its worth experimenting with the quantitiy, size and location of capacitors too. With careful construction/filtering I find that switched-mode  3.3v output from the pico is clean enough to get good results. You can eliminate the PSU as a source of noise by temporarily supplying the receiver components from a battery or other low-noise power source.

Another source of noise is switching currents from the PWM and Local Oscillator. I found that using a second inductor to provide a separate supply to the op-amp and input bias circuit (but not the analog switch) can help prevent LO switching noise from getting into the op-amp power supply.

One downside of breadboard construction is the lack of ground plane, it is possible to make significant improvements by giving careful thought to the ground connections. The biggest sources of noise are the local oscillator connection to the analog switch and the PWM connection to the headphones (and their respective ground return paths). The parts of the circuit most susceptible to noise are the inputs to the op-amp.

I found that providing a dedicated ground connection from the pico analog ground to the ground pins of the op-amp/sampling-capacitors/input bias-network and antenna ground (but not the analog switch) prevents any of the switching return currents flowing in the analog ground path. When I tried this I got quite a significant reduction in the noise floor with no antenna connected.

yasin112358, 2024-12-20:
thanks a lot, ı will check them out.

asflorenciotec, 2024-12-24:
Put a 1000uF 6,3v eletrolic capacitor near OLED display, kill the noise oled noise.

yasin112358, 2025-01-04:
I will try it thank you Jon .

24 Ara 2024 Sal, saat 04:59 tarihinde asflorenciotec <
***@***.***> şunu yazdı:

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

Tonytti, 2025-01-15:
If you don't have input passband filters you cannot use a miniwhip, because is a broadband antenna. I use a magnetic loop without filters, because the hi q of it, reception is excellent.

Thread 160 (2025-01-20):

TFT Spectrum Display is not right

ericeness, 2025-01-20:
I am working on v0.3 of my PicoRX hardware.  This version is built on a solderless breadboard with an improved layout, but that is not my issue.

I have noticed that the spectrum display at the receive frequency is duplicated at the -10 KHz portion of the display.  At the +10 KHz the spectrum is deleted.  For my picture I used a local AM radio station but I have observed the same thing on 40 Meter SSB.  I can hear 40 Meter SSB with the mode set to LSB, but I may have the I/Q sides swapped.

Could a wiring mistake on my part cause this artifact on the display?

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

dawsonjon, 2025-01-21:
@ericeness

Hi, I think theres more than one thing going on here.

1. Yes there is a known issue where the last approx 6kHz of the display wraps. It's an artefact of the IF frequency shift which is circular for discrete signals. There is some discussion about it here.

https://github.com/dawsonjon/PicoRX/issues/52#issuecomment-2341739419

2. Note that the duplication you are seeing is not caused by the issue above, the duplicate peak is an image. This suggests that either your I or Q channel has become disconnected which means the receiver can no-longer suppress images causing the spectrum to be mirrored.

3. The colours in the display are reversed. There is a menu option under hardware config to reverse this.

Cheers
Jon

ericeness, 2025-01-24:
> 2\. either your I or Q channel has become disconnected

Jon, thank you for your sage advice.  I got out my oscilloscope and sure enough, one of the opamp outputs was flatline.  I had the bright idea of using half of the mux for the I samples and the other side for the Q samples.  I connected both inputs together to make sure the same antenna signal reached both sides of the mux.  This approach shortens the analog path and simplifies the layout on a breadboard, or so I though.  I just don't get why only one half works.  I rewired to use only one half of the mux and boom, it worked as expected.

73, Eric

dawsonjon, 2025-01-24:
@ericeness great, glad you got it sorted!

penfold42, 2025-01-24:
> This approach shortens the analog path and simplifies the layout on a breadboard, or so I thought.  I just don't get why only one half works.
>
I took this approach with my second build - photos in the show us your build issue.
Is there a chance you had the unused outputs shorted ?

ericeness, 2025-01-25:
@penfold42
> I took this approach with my second build - photos in the show us your build issue.

Thank you confirming that my approach should work.  I took another pass at debugging.  I started moving the sample capacitors from one half of the mux to the other.  Once I found the capacitor that was not getting signal and confirmed that the wireless breadboard making a good connection, I concluded the issue was a bad solder joint on the TSSOP to dip adapter board.  I resoldered the pins on one half of the mux part and problem solved.  Now I can go back to my noise reduction experiments.

Thanks for the help,  Eric

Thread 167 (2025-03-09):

CAT on Windows

bugsel, 2025-03-09:
Thanks for the interesting project, yesterday I assembled the Pico RX, everything works fine, tested it only on FT8, on absolutely unsuitable antenna, on Linux the CAT interface works, but I can't launch it on Windows? The port appears, are there any special drivers needed for it?

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

bugsel, 2025-03-09:
Place for the OLED display does not match the most popular options that are sold: G-V) I didn't immediately understand, only after I burned my finger on the display)

dawsonjon, 2025-03-09:
@bugsel Hi, on windows you may need to set the force DTR (high) option to get CAT working. You are right about the old connections, I hadn't realised until recently that some olds were the other way round. When I update the PCB I will add some links.

bugsel, 2025-03-09:
@dawsonjon can use any display, there are 2 jumpers to change the polarity, can simply add labels to the pads on the mask

spanglz, 2025-03-16:
@bugsel did you ordered pcb? Are you from RU? And could you give me a contact for PCB ordering?

bugsel, 2025-03-17:
@spanglz I ordered from pcbwave, they accept ru cards on the website, delivery takes about a month, I have 10 of them, I can send one) p.s. same TG, write to me

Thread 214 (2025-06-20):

Schematic/Parts Layout for Rev 2 board

Tom-ak2b, 2025-06-20:
I have the Rev2 pcb but the only schematics and parts layout that I can find here don't match. Can someone point me to the proper ones.
Thanks

Tom-ak2b, 2025-06-20:
Thanks, that’s the one.

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

Closed 2025-06-26.

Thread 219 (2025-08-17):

Recieves signal after touching ground by hand

riyant56, 2025-08-17:
I have a small problem, the pi pico rx recieves signal after i touch the gnd of the pico then the signal is audible for a second and again fades away
I will tell the necessary info as the issue is acknowledged
Thanks 🙏

riyant56, 2025-08-19:
> The power in dBm is very low, and the noise floor isn't visible in the waterfall. That suggests to me that you aren't getting anything out of the op-amp. The noise from the op-amp should be visible on the spectrum scope even with no antenna connected. I would start by looking carefully at the op-amp circuit and work back towards the input.

Mr i have substituted 10uf electrolytic caps instead of the disc caps in the schematic
Is it the problem
Sorry for causing nuisance

riyant56, 2025-08-19:
i fixed it, the problem was  the caps were faulty in the op amp circuit
thanks Dawsonjon and Tonytti

Closed 2025-08-19.

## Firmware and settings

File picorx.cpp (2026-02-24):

#include "pico/stdlib.h"
#include <stdio.h>

#include "pico/multicore.h"
#include "pico/time.h"
#include "hardware/exception.h"
#include "hardware/watchdog.h"

#include "rx.h"
#include "ui.h"
#include "waterfall.h"
#include "cat.h"
#include "stack_watermark.h"

#define UI_REFRESH_HZ (10UL)
#define UI_REFRESH_US (1000000UL / UI_REFRESH_HZ)
#define CAT_REFRESH_US (1000UL) //1ms
#define BUTTONS_REFRESH_US (50000UL) // 50ms <=> 20Hz
#define WATERFALL_REFRESH_US (50000UL) // 50ms <=> 20Hz
#define STACK_UPDATE_US (1000000UL) // 1s

uint8_t spectrum[256];
uint8_t audio[128];
uint8_t dB10=10;
uint8_t zoom=1;
static rx_settings settings_to_apply;
static rx_status status;
static rx receiver(settings_to_apply, status);
static waterfall waterfall_inst(receiver);
static ui user_interface(settings_to_apply, status, receiver, spectrum, audio, dB10, zoom, waterfall_inst);

void core1_main()
{
    multicore_lockout_victim_init();
    receiver.run();
}

int main()
{

  // emergency bootloader mode
  gpio_init(PIN_BACK);
  gpio_set_dir(PIN_BACK, GPIO_IN);
  gpio_pull_up(PIN_BACK);
  if (gpio_get(PIN_BACK) == false) {
    reset_usb_boot(0, 0);
  }

  stdio_init_all();
  init_stack_watermark();
  watchdog_enable(2000, true);
  multicore_launch_core1(core1_main);

  // create an alarm pool for USB streaming with highest priority (0), so
  // that it can pre-empt the default pool
  receiver.set_alarm_pool(alarm_pool_create(0, 16));
  user_interface.autorestore();

  uint32_t last_ui_update = 0;
  uint32_t last_cat_update = 0;
  uint32_t last_waterfall_update = 0;
  uint32_t last_stack_update = 0;

  while(1)
  {

    watchdog_update();

    //schedule tasks
    if(sem_try_acquire(&receiver.i2c_semaphore))  {
      if(time_us_32() - last_ui_update > UI_REFRESH_US)
      {
        last_ui_update = time_us_32();
        user_interface.do_ui();
        receiver.get_spectrum(spectrum, dB10, zoom);
        receiver.get_audio(audio);
      }
      sem_release(&receiver.i2c_semaphore);
    }

    if(time_us_32() - last_cat_update > CAT_REFRESH_US)
    {
      last_cat_update = time_us_32();
      process_cat_control(settings_to_apply, status, receiver, user_interface.get_settings());
    }

    if(time_us_32() - last_waterfall_update > WATERFALL_REFRESH_US)
    {
      last_waterfall_update = time_us_32();
      waterfall_inst.update(user_interface.get_settings(), settings_to_apply, status, spectrum, dB10, zoom);
    }

    if(time_us_32() - last_stack_update > STACK_UPDATE_US)
    {
      last_stack_update = time_us_32();
      #ifdef PRINT_STACK_USAGE
      print_stack_usage();
      #endif
    }

  }
}

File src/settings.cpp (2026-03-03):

#include "settings.h"
#include "autosave_memory.h"
#include "memory.h"
#include <hardware/flash.h>
#include "pico/multicore.h"
#include <cstring>

void apply_settings_to_xcvr(xcvr & transceiver, xcvr_settings & xcvr_settings, s_settings & settings, bool suspend, bool settings_changed)
{
  transceiver.access(settings_changed);
  xcvr_settings.tuned_frequency_Hz = settings.channel.frequency;
  xcvr_settings.agc_setting = settings.channel.agc_setting;
  xcvr_settings.agc_gain = settings.global.agc_gain;
  xcvr_settings.enable_auto_notch = settings.global.enable_auto_notch;
  xcvr_settings.enable_noise_reduction = settings.global.enable_noise_reduction;
  xcvr_settings.mode = settings.channel.mode;
  xcvr_settings.volume = settings.global.volume;
  xcvr_settings.squelch_threshold = settings.global.squelch_threshold;
  xcvr_settings.squelch_timeout = settings.global.squelch_timeout;
  xcvr_settings.step_Hz = step_sizes[settings.channel.step];
  xcvr_settings.cw_sidetone_Hz = settings.global.cw_sidetone*100;
  xcvr_settings.gain_cal = settings.global.gain_cal;
  xcvr_settings.suspend = suspend;
  xcvr_settings.swap_iq = settings.global.swap_iq;
  xcvr_settings.bandwidth = settings.channel.bandwidth;
  xcvr_settings.deemphasis = settings.global.deemphasis;
  xcvr_settings.band_1_limit = settings.global.band1;
  xcvr_settings.band_2_limit = settings.global.band2;
  xcvr_settings.band_3_limit = settings.global.band3;
  xcvr_settings.band_4_limit = settings.global.band4;
  xcvr_settings.band_5_limit = settings.global.band5;
  xcvr_settings.band_6_limit = settings.global.band6;
  xcvr_settings.band_7_limit = settings.global.band7;
  xcvr_settings.ppm = settings.global.ppm;
  xcvr_settings.iq_correction = settings.global.iq_correction;
  xcvr_settings.if_mode = settings.global.if_mode;
  xcvr_settings.if_frequency_hz_over_100 = settings.global.if_frequency_hz_over_100;
  xcvr_settings.noise_estimation = settings.global.noise_estimation + 8;
  xcvr_settings.noise_threshold = settings.global.noise_threshold;
  xcvr_settings.spectrum_smoothing = settings.global.spectrum_smoothing;
  xcvr_settings.enable_external_nco = settings.global.enable_external_nco;
  xcvr_settings.treble = settings.global.treble;
  xcvr_settings.bass = settings.global.bass;
  xcvr_settings.stream_raw_iq = settings.global.usb_stream;
  xcvr_settings.tuning_option = settings.global.tuning_option;
  xcvr_settings.impulse_threshold = settings.global.impulse_threshold;

  xcvr_settings.test_tone_setting = settings.global.test_tone_setting;
  xcvr_settings.test_tone_frequency = settings.global.test_tone_frequency;
  xcvr_settings.cw_paddle = settings.global.cw_paddle;
  xcvr_settings.cw_speed = settings.global.cw_speed;
  xcvr_settings.mic_gain = settings.global.mic_gain;
  xcvr_settings.tx_modulation = settings.global.tx_modulation;
  xcvr_settings.pwm_min = settings.global.pwm_min;
  xcvr_settings.pwm_max = settings.global.pwm_max;
  xcvr_settings.pwm_threshold = settings.global.pwm_threshold;
  xcvr_settings.tx_phase_dither = settings.global.tx_phase_dither;
  xcvr_settings.tx_i_offset = settings.global.tx_i_offset;
  xcvr_settings.tx_q_offset = settings.global.tx_q_offset;
  xcvr_settings.tx_iq_balance = settings.global.tx_iq_balance;
  xcvr_settings.tx_use_best_clock = settings.global.tx_use_best_clock;
  xcvr_settings.tx_monitor = settings.global.tx_monitor;
  xcvr_settings.tx_speech_processor = settings.global.tx_speech_processor;
  xcvr_settings.tx_band_limits = settings.global.tx_band_limits;


  transceiver.release();
}

s_memory_channel get_channel(uint16_t channel_number)
{
  static_assert(sizeof(s_memory_channel) < memory_chan_size*4);
  s_memory_channel memory_channel;
  memcpy(&memory_channel.channel, radio_memory[channel_number], sizeof(s_memory_channel));
  memory_channel.label[16] = 0; //add null terminator
  return memory_channel;
}
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

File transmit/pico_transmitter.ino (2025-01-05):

//  _  ___  _   _____ _     _
// / |/ _ \/ | |_   _| |__ (_)_ __   __ _ ___
// | | | | | |   | | | '_ \| | '_ \ / _` / __|
// | | |_| | |   | | | | | | | | | | (_| \__ \
// |_|\___/|_|   |_| |_| |_|_|_| |_|\__, |___/
//                                  |___/
//
// Copyright (c) Jonathan P Dawson 2023
// filename: transmitter.cpp
// description: Ham Transmitter for Pi Pico 
// License: MIT
//

// Transmitter example with serial interface
// Supports serial streaming of audio data using
// transmit.py utility

#define BALANCED //comment out for polar amplifier
#define MICROPHONE //comment out for SERIAL mode

#include "transmit.h"

// example application
void setup() 
{
  Serial.begin(12000000);
}

uint32_t frequency = 14250000;
tx_mode_t mode = USB;
void loop()
{
  
  #ifdef MICROPHONE


  //transmit audio from microphone
  transmit(mode, frequency, false);
  
  
  #else
  
  
  //transmit audio from USB serial port
  Serial.println("Pi Pico Transmitter>");    
  while(!Serial.available()) delay(100);
  int command = Serial.read();
  switch (command) {
    // set frequency
    case 'f':
      frequency = Serial.parseInt();
      Serial.print("Frequency: ");
      Serial.println(frequency);
      break;

    // set mode
    case 'm':
      while(!Serial.available()) delay(100);
      command = Serial.read();
      if (command == 'a') {
        Serial.println("MODE=AM");
        mode = AM;
        break;
      } else if (command == 'f') {
        Serial.println("MODE=FM");
        mode = FM;
        break;
      } else if (command == 'l') {
        Serial.println("MODE=LSB");
        mode = LSB;
        break;
      } else if (command == 'u') {
        Serial.println("MODE=USB");
        mode = USB;
        break;
      }
      break;

    // transmit serial data
    case 's':
      Serial.println("Starting transmitter...");
      transmit(mode, frequency, true);
      Serial.println("Transmitter timed out...");
      break;

    // help
    case '?':
      Serial.println("Serial Interface Help");
      Serial.println("=====================");
      Serial.println("fxxxxxx, set frequency Hz");
      Serial.println("mx, set mode, a=AM, f=FM, l=LSB, u=USB");
      Serial.println("s, transmit serial data - (timeout terminates)");
      Serial.println("?, Help (this message)");
      break;
  }
  Serial.println("Pi Pico Transmitter>");


  #endif
}

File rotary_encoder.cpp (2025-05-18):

#include "rotary_encoder.h"

#include "quadrature_encoder.pio.h"
#include "ui.h"
#include "pins.h"


rotary_encoder::rotary_encoder(s_global_settings &settings) : encoder(settings) {
  gpio_set_function(PIN_AB, GPIO_FUNC_PIO1);
  gpio_set_function(PIN_AB + 1, GPIO_FUNC_PIO1);
  uint offset = pio_add_program(pio, &quadrature_encoder_program);
  quadrature_encoder_program_init(pio, sm, offset, PIN_AB, 1000);

  if (settings.encoder_resolution) {
    new_position = -((quadrature_encoder_get_count(pio, sm) + 1) / 2);
  } else {
    new_position = -((quadrature_encoder_get_count(pio, sm) + 2) / 4);
  }

  old_position = new_position;
}

int32_t rotary_encoder::get_change(void) {
  if (settings.encoder_resolution) {
    new_position = -((quadrature_encoder_get_count(pio, sm) + 1) / 2);
  } else {
    new_position = -((quadrature_encoder_get_count(pio, sm) + 2) / 4);
  }
  int32_t delta = new_position - old_position;
  old_position = new_position;
  if (settings.reverse_encoder & 1) {
    return -delta;
  } else {
    return delta;
  }
}

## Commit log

2023-01-16 experiment with DMA chaining
2023-01-16 ping pong dma working
2023-01-17 chained DMA for adc and pwm working
2023-01-18 Replace some magic numbers with constants
    [picorx.cpp, rx.cpp, rx_definitions.h]
2023-01-24 Add quadrature encoder and OLED display
2023-02-02 Add squelch and fix smeter
    [rx.cpp, rx_definitions.h, ui.cpp]
2023-02-03 work out number of audio samples on the fly
2023-02-12 Add Store, battery voltage and core temperature monitor
2023-07-05 Add PCB design
    [Bandpass.kicad_sch, back_panel.kicad_pcb, back_panel.kicad_sch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]
2023-07-14 Get CW working
    [Lowpass.kicad_sch, Preamplifier.kicad_sch, back_panel.kicad_pcb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]
2023-07-14 Make NCO avoid tuned frequency
    [rx.cpp, rx_definitions.h]
2023-07-16 Prepare PCB for manufacture
    [Preamplifier.kicad_sch, pi_pico.kicad_sch, pico_rx.kicad_pcb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]
2023-07-16 Add gerbers
    [Preamplifier.kicad_sch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]
2023-07-16 Fix page erase hang
    [pico_rx.kicad_pcb]
2023-07-17 Use flash to remember settings between power cycles, uses a simple wear leveling scheme
2023-07-27 Update memory files, Update schematic
    [qsd.kicad_sch]
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2023-07-31 Update power calculation
    [Preamplifier.kicad_sch, pi_pico.kicad_sch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]
2023-08-03 Fix intermittent loss of audio after suspending receiver, DMA channels not stopping cleanly leading to loss of synchronisation with I/Q data.
    [rx.cpp, ui.cpp]
2023-08-05 Remove overflow issue in power meter
    [ui.cpp]
2023-08-09 Add BOM
    [BOM.ods]
2024-02-12 Use encoder button as shortcut to recall menu for fast navigation
    [ui.cpp]
2024-03-15 Add component layout PDF
    [pico_rx.kicad_pcb]
2024-03-21 Fix incorrect use of adc_gpio_init
    [rx.cpp]
2024-03-23 Add scale to spectrum scope, add simple battery monitor utility
2024-04-12 Correct error in schematic
    [pico_rx.kicad_pcb, qsd.kicad_sch]
2024-06-15 Add capability to swap IQ channels and reverse encoder direction
    [rx.cpp, ui.cpp]
2024-06-23 Improve frequency resolution by making small adjustments to system clock. Add utility to upload memory contents over USB
    [Preamplifier.kicad_sch, audio.kicad_sch, memory.csv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]
2024-07-28 Update PCB design to fix issues found
    [BOM.ods, Preamplifier.kicad_sch, audio.kicad_sch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]
2024-08-05 Take spectrum scope after second half band filter
2024-08-11 Add 3D printed enclosure for breadboard version
    [breadboard_radio-Partback panel.stl, breadboard_radio-Partback_panel.stl, breadboard_radio-Partbox.stl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]
2024-08-11 Correct placement of USB cutout
    [breadboard_radio-Partbox.stl, breadboard_radio.FCStd]
2024-08-11 Fix error in schematic
    [concept.kicad_sch]
2024-08-17 Fix encoder issue when uding pi pico 2
    [ui.cpp]
2024-08-26 Add speaker
    [breadboard_radio-PartSpeakerLid.stl, breadboard_radio-Partfront_panel.stl, breadboard_radio.FCStd]
2024-08-28 Added menu item to flip oled display 180 degrees
    [ui.cpp]
2024-08-29 Use FFT based filter
2024-08-30 Seperate nco initialisation from nco frequency adjustment. Adjust PWM wrap to best match clock frequency
2024-08-31 Fix off by 1 error in squelch menu items
    [ui.cpp]
2024-08-31 WIP: can now set a gain calibration figure for the S meter
2024-09-01 show message before rebooting into upload mode
    [ui.cpp]
2024-09-01 another fix for oled writing. This time we allocate 129 bytes per page to make room for the 0x40 at the start of each I2C transmission
2024-09-02 Add automatic notch filter
2024-09-03 Menus now use double size font
    s/display_print/display_print_str/ and s/display_write/display_print_char/
    display_print_char, display_print_num, display_print_str:
    - added a style bitfield. style_reversed style_centered so far
    display_print_str:
    supports \n for new line
    supperts \a to toggle text reverse font
    fixed out by 1 error in PSU mode menu
    added vim backup files to gitignore
    [ui.cpp]
2024-09-04 Show memory upload progress by inverting the display colours
    Consolidated USB upload menus into one
    reworked print_menu_option.
    - use strtok to split the options#list#
    - if only 2 options and they'd fit, print them both with highlight
    added display_print_freq()
    Added style_nowrap. extra characters just get ignored
    Added style_right to print stuff to..... the right
    Added (harmless) missing trailing # on a couple of enumerate_entry calls
    [ui.cpp]
2024-09-04 recall menu: - prints frequency in 2X - prints name in 2X if it'll fit, else 1x - now skips blank entries when browsing through - remembers which memory you last selected if you use the menu button -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
    [ui.cpp]
2024-09-05 reuse print_enum_option in string_entry and frequency_entry
    menu_entry and enumerate_entry work out the "max" value from the options list
2024-09-06 Add filter bandwidth indicator
2024-09-06 Refactored IO (mostly buttons) handling
    Some adjustments
2024-09-06 Another minor button mode fix
    [ui.cpp]
2024-09-07 vscode doesnt like uint.
    bounds check in print_enum_option
2024-09-07 string_entry() : tweaked scrolling and added visual scroll bar
    reworked previous enum bounds check
    [ui.cpp]
2024-09-07 Make use of the PUSH button where possible
2024-09-08 Store can now delete a memory
    added display_draw_separator(uint16_t y, uint32_t scale=1, bool colour=1); to draw either 1px, 2px or 3px separator
    added display_get_x and display_get_y
    added display_clear_str(uint32_t scale, bool colour); to clears current line of text, cursor pos is unchanged
    removed display_line1 and line2
    other bits of tidying
2024-09-08 Adjust scaling of data to avoid overflow with strong stations
    [rx_definitions.h]
2024-09-10 Fix immediate lockup after upload that occured 90% of the time. Oddly a usb remove insert didnt exihibit this.
    Took ages to track down, but min_r was -inf so the loop never iterated
    [ui.cpp]
2024-09-10 Some float range fixes
    [ui.cpp]
2024-09-11 Pressing Menu on home page switches between multiple home pages
    moved existing code draw_spectrum()
    - now takes a starting Y pixel position and draws from there to pixel 63
    moved steps[] and smeter[] strings to globals
2024-09-12 Refactored splashscreen animation. no longer blocks and button press/encoder moves will abort it
    [ui.cpp]
2024-09-13 Fix bug in print_enum_option re: 2 option string length checking
    [ui.cpp]
2024-09-13 WIP Add display scrolling ssd1306_scroll_screen(&disp, x, y ); - Y scrolling seems to work - X positive fails badly - X -1 might work - X -4 crops the right edge
    [ui.cpp]
2024-09-14 Added signal strength to Recall page - left some commented out style options in for now
    factred out int ui::dBm_to_S(float power_dBm);
2024-09-14 renderpage_* now know if they've just been switched to - so the can reinit if required
    tidying:
    s/recall/memory_recall/
    s/store/memory_store/
    s/update_display/renderpage_original/
    s/update_display2/renderpage_bigspectrum/
    s/update_display3/renderpage_waterfall/
    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
2024-09-14 Reworked recall signal strength to be vertical bar
    [ui.cpp]
2024-09-14 top level menu no longer quits to home after an action - except Recall - you're probably done with the menus then...
    [ui.cpp]
2024-09-14 last merge fixup for menu not exiting
    [ui.cpp]
2024-09-15 Fixed audio clicking in the 'Recall' screen
    [ui.cpp]
2024-09-15 fix for Menu up no longer goes home - the changes never made it to the radio side
    [ui.cpp]
2024-09-16 display_draw_str and char again support arbitrary scaling of fonts. - if odd, scale the 8x6; if even scale the 16x12 - fixes my splash screen :)
    ssd1306_draw_char_with_font()
    fix logic on preclearing background of character cell.
    - if drawing black, clear with white
    - if drawing white, clear with black
    - if colour==2, do nothing so OR/XOR drawing works
    [ui.cpp]
2024-09-16 fic draw_h_tick_marks() wrong Y offset on a couple of the ticks
    [ui.cpp]
2024-09-16 Fix waterfall scrolling some crumbs down
    [ui.cpp]
2024-09-16 Use power_dBm for better resolution
2024-09-17 ticks can be labelled
    renamed some variables
    fixed off by 1 on tick count
    fixed init of dBm averages to be -FLT_MAX
    [ui.cpp]
2024-09-17 Add slow ramping of audio to prevent clicks and pops on power up and during frequency change
    [rx.cpp]
2024-09-17 Fix speaker popping during power on and tuning
    [rx.cpp]
2024-09-17 Fix freeze when attempting to store
    [rx.cpp]
2024-09-18 Analog meter returns if you ask for height zero (rather than crash with DIV0)
    Analog meter can draw a rectangular style with a negative height.
    [ui.cpp]
2024-09-18 memory_scan() speed display uses new double height font
    display_print_char() can print in style_xor
2024-09-19 refresh display when you pause with encoder button
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2024-09-19 Moved de-emphasis setting to rx_features
2024-09-19 Added plots to deemphasis filter design script
2024-09-19 Fixed periodic audio cut out
    [rx.cpp]
2024-09-20 fix subtle bug where on exiting display_timeout, you'd get dropped into another hw_config menu based on the selected timeout :)
    oled contrast is now stored in bits of hw_setup
    s/enum_deemphasis/flag_deemphasis
    added mask_deemphasis
    [ui.cpp]
2024-09-20 scan_frequency: long press on "back" -> adjust squelch short press on back -> quit and restore radio settings
    long press on "menu" -> adjust mode
    short press on menu -> select station and quit
    [ui.cpp]
2024-09-21 factored out draw_vertical_dBm( 124, power_dBm);
    created dBm_to_63px(float power_dBm);
2024-09-21 Added scanner_radio_menu() with a subset of the main menu for quicker access in the scanner
    any press on back -> quit and restore radio settings
    short press on "menu" -> launches scanner_radio_menu()
    long press on menu -> select station and quit
    [ui.cpp]
2024-09-21 Make band filters configurable
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2024-09-25 Can now set encoder resolution. Suits encoders with twice as many pulses per indent
2024-10-01 Reverted relabeling to avoid Linquistic warfare
    USB audio is grabbed after the AGC with no scaling
    [ui.cpp]
2024-10-01 Make volume controllable via encoder
2024-10-01 Refactor of button handling
2024-10-02 Fixed bu at high zoom levels
    [ui.cpp]
2024-10-02 Further small button handling adjustments and volume bar display change
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2024-10-02 Fixed one event type
    [ui.cpp]
2024-10-03 Fix scanner button logic to a) work again and b) benefit from the short/long logic rather than my own
    [ui.cpp]
2024-10-03 Moved encoder to the rest of the events
2024-10-03 Added u8g2 and merged it with current display driver
2024-10-04 M_PI to keep vscode from flagging problems
    fix splash screen button/encoder handling
    move some code out of button_state computation
    - I want to separate out the button_state computation for use elsewhere
    - moved any code that doesn't contribute to this
    [ui.cpp]
2024-10-04 Home double tap takes you to page 0
    fixed stupid missing braces error :)
    [ui.cpp]
2024-10-04 Changed scanner buttons Back short click => exit rollback settings Back long press => exit keep current settings Menu short click => Radio options Menu long click => does nothing now
    [ui.cpp]
2024-10-04 Fixed scanner bug when squelch == 0
    increase scanning speed
    [ui.cpp]
2024-10-04 submodules - add u9g2 - remove pico-ssd1306 (but not "our" used files)
2024-10-08 Switched to fixed 15k samplerate
    [picorx.cpp, rx.cpp, rx_definitions.h]
2024-10-08 Added button mode control + some minor refactoring
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2024-10-09 Use display power control functions from u8g2 and reduce the number of locations
    the display is refreshed from
2024-10-09 Fixed the timer configuration...
    [picorx.cpp]
2024-10-10 various tweaks and bugfixes
    [ili934x.cpp, picorx.cpp, rx.cpp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]
2024-10-13 Fix build for pico2
    [ili934x.cpp, waterfall.cpp]
2024-10-17 Play around with IQ imbalance correction, and add some CPU optimisations
    [rx.cpp, ui.cpp]
2024-10-17 Fix 9kHz step size issue
    [rx.cpp, ui.cpp]
2024-10-18 Power down TFT after timeout, add audio interpolation
2024-11-10 Various bug-fixes and tweaks
    [breadboard_radio-Partback_panel_tft.stl, breadboard_radio-Partbox.stl, breadboard_radio-Partfront_panel_tft.stl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]
2024-11-26 When using AGC, AGC gain specifies maximum gain, in manual mode, a fixed AGC gain is applied
    [rx.cpp, ui.cpp]
2024-12-08 First attempt at noise reduction
    [rx.cpp, ui.cpp]
2024-12-08 tweaks to noise reduction
    [ui.cpp]
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2025-01-05 Make sure rf and magnitude pin are driven low when not transmitting
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2025-01-11 Add refinements to PWM generation and add iambic CW keyer
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2025-01-26 Replace settings with a struct
    [rx.cpp, settings.cpp, ui.cpp]
2025-01-27 Get memory uploading to work
    [memory.csv]
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2025-03-31 Add missing break statement
    [ui.cpp]
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2025-04-05 Remove reset from waterfall
    [ili934x.cpp, waterfall.cpp]
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2025-05-02 Added simple /noise canceler/spectral subtraction/
    [rx.cpp, ui.cpp]
2025-05-03 Added another mode to the noise canceler
    [rx.cpp, ui.cpp]
2025-05-03 Fixed USB volume setting
    [rx.cpp]
2025-05-04 Fixed "UI feedback" problem when setting encoder resolution
    [ui.cpp]
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2025-05-07 Fixed scaling in low-pass filter
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2025-05-11 Set the correct DMA channel
    [rx.cpp]
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2025-05-18 update pins and simulate adaptive noise setting
    [pins.h, rx.cpp, waterfall.cpp]
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2025-05-19 Move the busy time measurement past the PWM interpolation and syncing
2025-05-20 Update CAT to include memory up/download, and a couple of other fixed
    [contents.csv]
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2025-05-21 Fixed the busy time measurement
    [rx.cpp]
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2025-06-01 Fix error in filter smoothing
2025-07-03 Temporarily set GPIO10 high, (was TFT reset)
    [picorx.cpp]
2025-07-03 fix freq cal issue
    [rx.cpp]
2025-07-20 Add noise reduction animation and update concept schematic
    [concept.kicad_sch]
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2025-09-14 Added synchronous demodulator state resetting
    [rx.cpp]
2025-09-23 Added simple impulse noise blanker
    [rx.cpp, settings.cpp, ui.cpp]
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2025-10-15 Re-added synchronous AM demodulator state resetting
    [rx.cpp]
2025-10-18 Make the waterfall a little bit more informative by subtracting rough
    noise floor estimate
    [ui.cpp]
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2026-02-16 Correct band menu label
    [rx.cpp, settings.cpp, ui.cpp]
2026-02-21 Rescale filters to avoid any possibility of overflow
2026-02-22 Update modulator so that I and Q are correctly generated in all modes
    [rx.cpp]
2026-02-27 Reduce sample rate when using external polar modulator
2026-02-28 Start drawing xcvr concept schemetic
    [BOM.ods, Lowpass.kicad_sch, Preamplifier.kicad_sch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]
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
